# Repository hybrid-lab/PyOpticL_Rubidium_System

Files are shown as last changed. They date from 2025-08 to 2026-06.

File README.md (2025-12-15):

# Rb87 Neutral Atom Optical Platform (PyOpticL + FreeCAD)

This repository contains a PyOpticL-based optical/mechanical layout for building an optical platform targeting Rb-87 neutral atom experiments. It assembles a complete, code-driven CAD model in FreeCAD, organizing the setup into modular boards.

The project originates from (and depends on) PyOpticL, a code-to-CAD tooling framework for modular optics systems engineering, and uses FreeCAD as the CAD backend.

- Project webpage (origin): https://github.com/UMassIonTrappers/PyOpticL
- Affiliation: UC Berkeley, Department of Physics — Prof. Sulyemanzade’s research group
- Lab website: https://suleymanzadelab.com/
- Collaborators:
  - University of Wisconsin-Madison - Prof. Sinclair's research group - https://sinclair.physics.wisc.edu/
  - Dr. Brandon Grinkemeyer, Harvard University (Postdoctoral Researcher) — https://lukin.physics.harvard.edu/people/brandon-grinkemeyer

---
## Overview

- Purpose: Build a modular optical platform for Rb-87 neutral atom quantum computing.
- CAD Backend: FreeCAD
- Optical/CAD Tooling: PyOpticL
- Project Structure: The system is organized into these main boards:
  - Reference_board
  - Laser_board
  - Repumper_board
  - Spectroscopy_board
  - TA_board
  - AOM_board

## Prerequisites

- FreeCAD (latest stable recommended)
- PyOpticL module installed in FreeCAD

---

## Installation

1. Install FreeCAD on your system.
2. Install PyOpticL in FreeCAD, following the official instructions at https://github.com/UMassIonTrappers/PyOpticL.
3. Update the PyOpticL module directory with this project’s assets:
   - Copy the `stl` folder from this repository into the PyOpticL module’s directory.
   - Copy `optomech.py` from this repository into the PyOpticL module’s directory, replacing the existing file if present.

Note: The exact PyOpticL module path depends on your OS and FreeCAD configuration (e.g., on macOS it may be under `~/Library/Application Support/FreeCAD/Mod/PyOpticL/PyOpticL`).

## Project Files

- `stl/` — Mechanical part models used by the layout (mounts, adapters, etc.) in stl format.
- `optomech.py` — Project-specific mechanical and optical component definitions/overrides for PyOpticL.
- `Adapters/` - 3D\-printable files(most of them are in step format) for the adapters on the boards, along with the Rb cell holders.
- Main script: See the provided Python script (e.g., “PyOpticL_Rubidium_System”) that constructs all boards in FreeCAD using PyOpticL.

---

## Boards

- Reference_board:
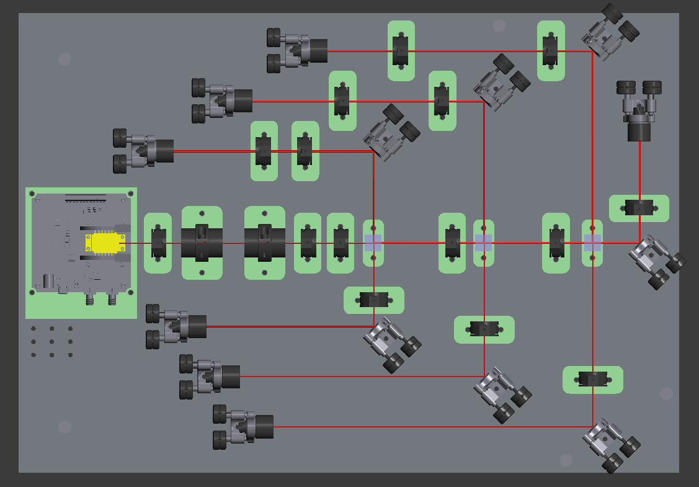
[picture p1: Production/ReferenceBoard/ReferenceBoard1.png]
The schematic of reference board in FreeCAD(front view))

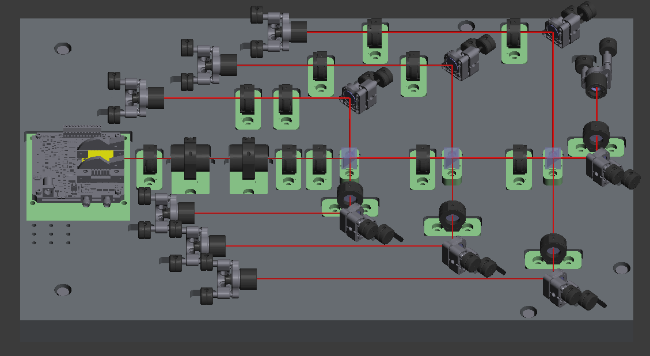
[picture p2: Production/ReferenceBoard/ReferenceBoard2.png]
The schematic of reference board in FreeCAD(top view)

  After exiting the laser, the main beam passes through polarizing elements and isolators, then through several PBSs before entering the fiber, which leads to the Spectroscopy board for frequency locking. Three beams, including the MOT light and Repump light, are each combined with side beams split from the main beam by PBSs, using beatnote technology to achieve frequency locking of these beams.<br><br>

---

- Laser_board:
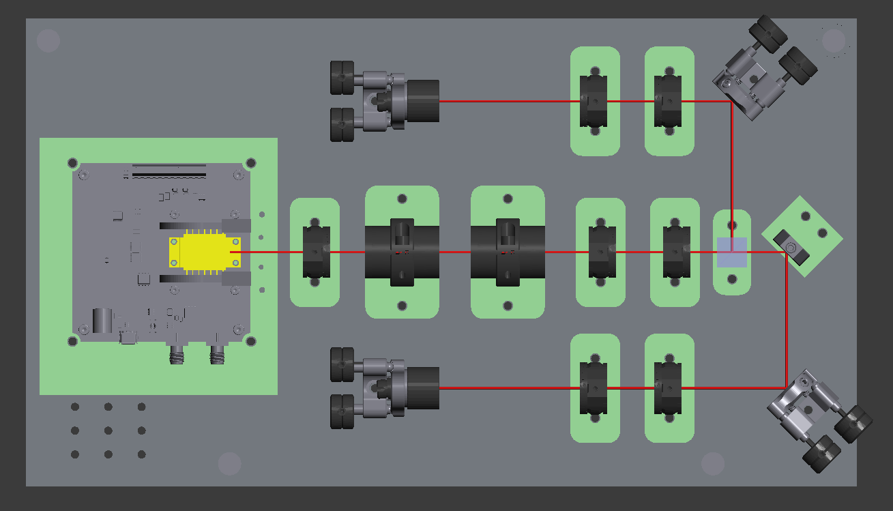
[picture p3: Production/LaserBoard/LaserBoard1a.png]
The schematic of Laser board1 in FreeCAD(front view)
 
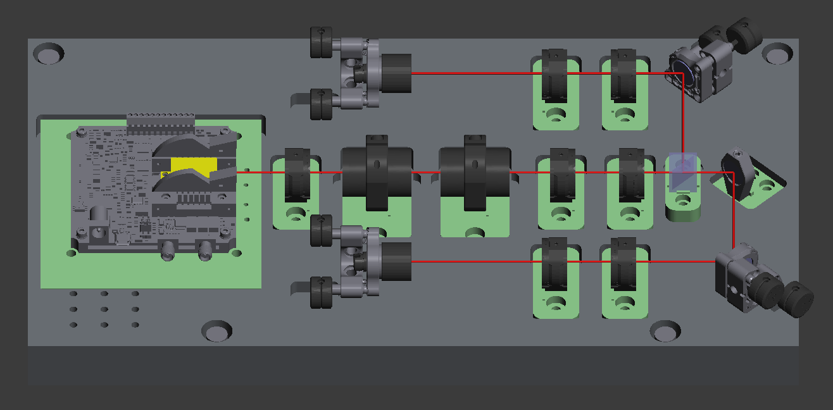
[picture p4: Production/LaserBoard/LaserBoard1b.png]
The schematic of Laser board1 in FreeCAD(top view)
 
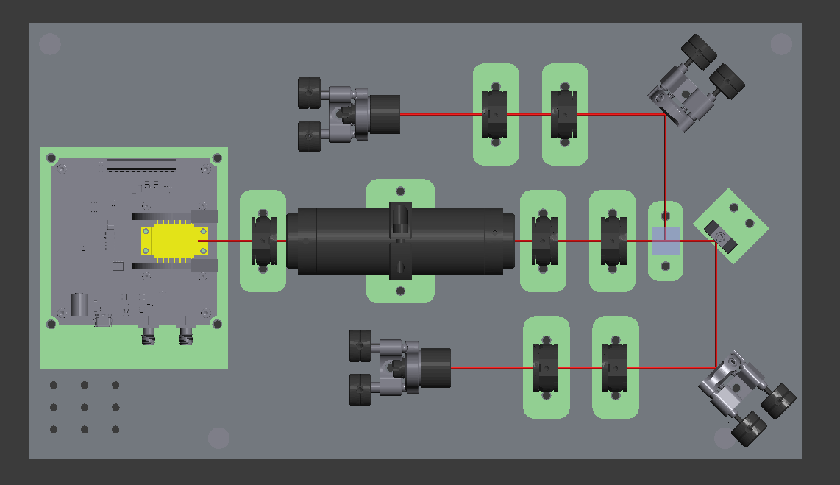
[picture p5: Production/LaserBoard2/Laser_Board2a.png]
The schematic of Laser board2 in FreeCAD(front view)
 
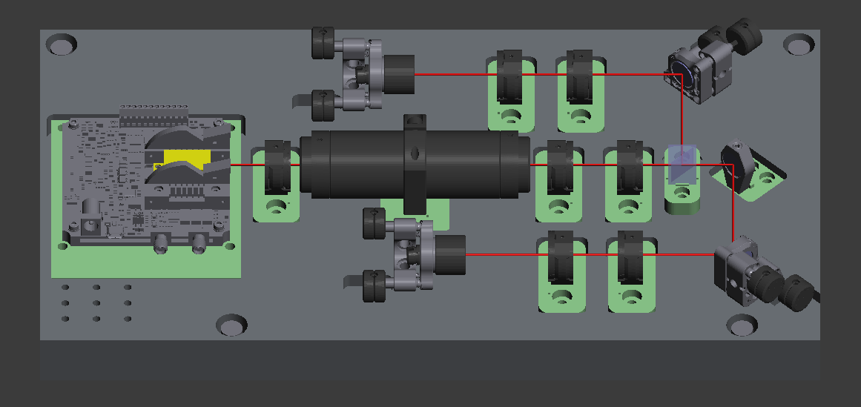
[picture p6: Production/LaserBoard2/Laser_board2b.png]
The schematic of Laser board2 in FreeCAD(top view)
 
The Laser board’s beam splits into two paths: one for various operations (Like MOT and Repumper) and one to the Reference board for frequency locking. 
Because of different types of isolators we may using, there are two versions of the Laser board.<br><br>

---

- Repumper_board:
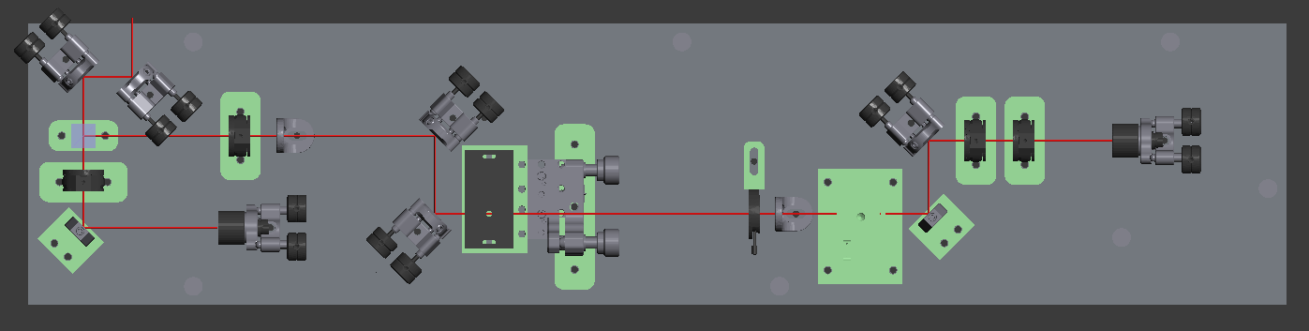
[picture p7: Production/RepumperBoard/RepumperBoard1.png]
The schematic of repumper board in FreeCAD(front view)

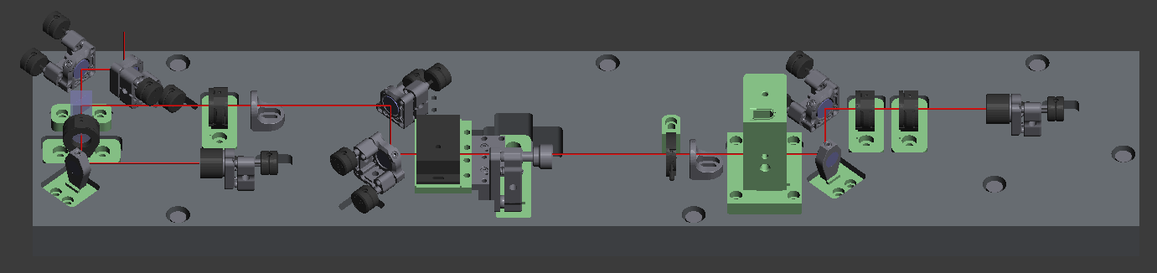
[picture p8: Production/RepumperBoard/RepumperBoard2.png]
The schematic of repumper board in FreeCAD(top view)

The laser board output is sent via fiber to the repumper board (lower left), where a PBS splits it into two beams: one directed to the AOM board (which we likely won’t use for repumping), and the other passing through an AOM and shutter into a fiber.<br><br>

---

- Spectroscopy_board:
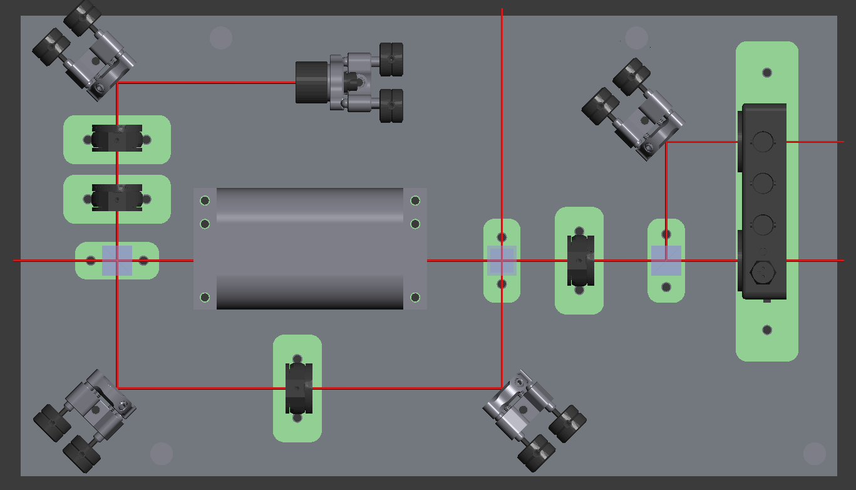
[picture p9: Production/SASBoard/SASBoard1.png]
The schematic of spectroscopy board in FreeCAD(front view)

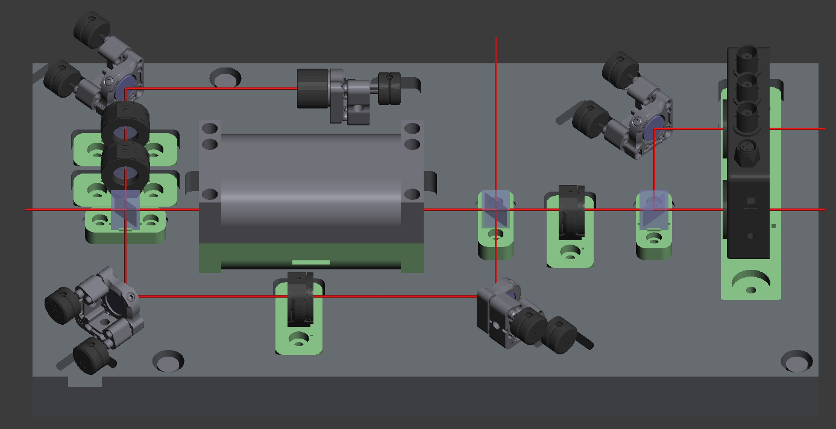
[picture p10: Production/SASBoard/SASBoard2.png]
The schematic of spectroscopy board in FreeCAD(top view)

After going through the reference board, the main beam splits into two beams, one strong(pump) and one weak(probe), which counterpropagate through the Rb atomic vapor at this board. The stronger beam finally goes to the photodetector. Here we use the Saturation absorption spectroscopy method, which will selectively saturate zero-velocity atoms in a vapor, producing a narrow Lamb dip that overcomes Doppler broadening and provides a stable reference for high-precision laser frequency locking.<br><br>

---

- TA_board: 
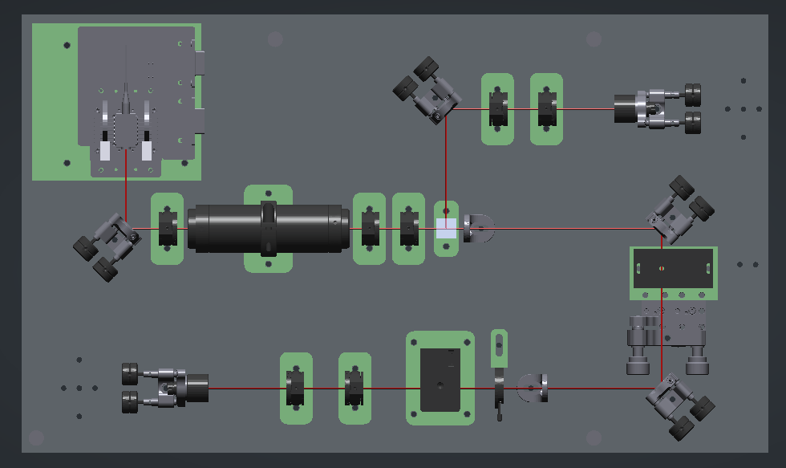
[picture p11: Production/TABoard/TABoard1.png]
The schematic of TA board in FreeCAD(front view)

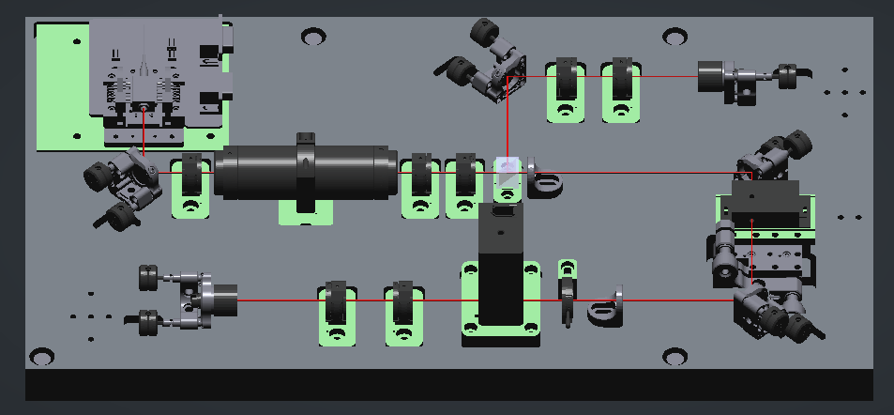
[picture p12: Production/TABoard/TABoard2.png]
The schematic of TA board in FreeCAD(top view)

On this board, a tapered amplifier boosts the laser power before passing it through a -60 dB isolator. The beam is then split into two paths: one leads directly to a fiber for possible coarse locking, while the other passes through an AOM and a shutter before entering a fiber for operations.

---

- AOM_board:
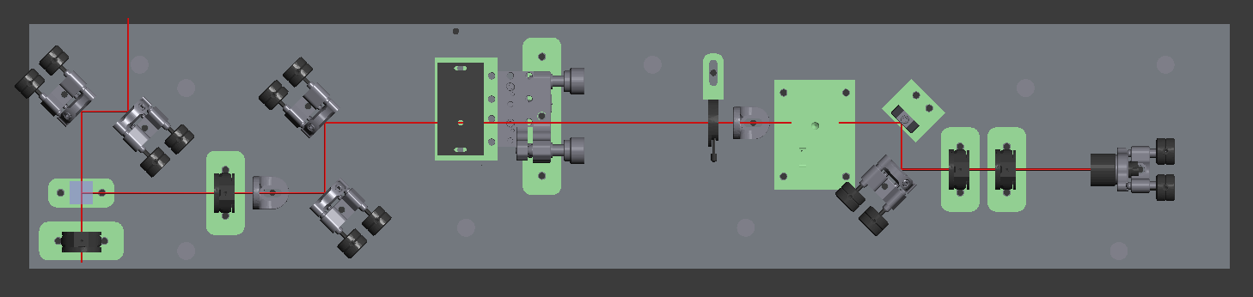
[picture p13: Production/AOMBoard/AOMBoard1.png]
The schematic of AOM board in FreeCAD(front view)

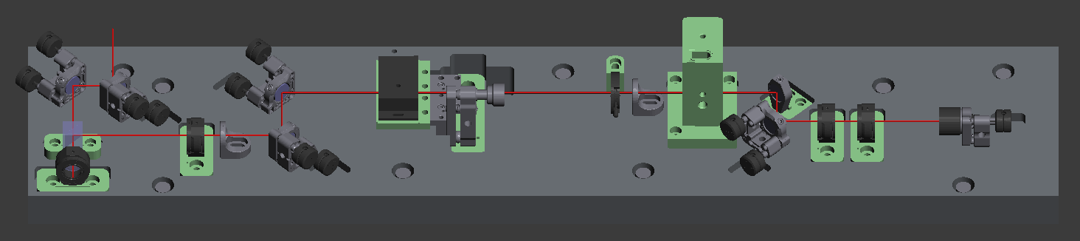
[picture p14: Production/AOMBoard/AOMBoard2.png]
The schematic of AOM board in FreeCAD(top view)

After the TA board, we split the beam into multiple paths, couple each into an optical fiber, and equip each path with an AOM and shutter for switching. This is achieved by combining the Repumper board and AOM board. The TA output is sent via fiber to the repumper board, where a PBS divides it into two beams: one is routed to the appropriately positioned AOM board, and the other passes through an AOM and shutter into a fiber. The beam entering the AOM board is split again: one branch feeds the next AOM board, and the other is coupled into a fiber. This way, we can control the number of beams by adjusting the number of AOM boards.

---
## How to Use

Please see the Quickstart Guide in the PyOpticL wiki:
https://github.com/UMassIonTrappers/PyOpticL/wiki#quickstart-guide

---

## Acknowledgments

**Developed through a collaborative effort between the Department of Physics at the [University of California, Berkeley](https://suleymanzadelab.com/) (Prof. Sulyemanzade’s group) and the [University of Wisconsin–Madison](https://sinclair.physics.wisc.edu/) (Prof. Sinclair’s research group).**  
Additional contributions were provided by [Dr. Brandon Grinkemeyer](https://lukin.physics.harvard.edu/people/brandon-grinkemeyer) (Harvard University, Lukin Group).

The project builds on **PyOpticL**, a code-to-CAD optical layout tool enabling parametric and modular optics design within **FreeCAD**, an open-source parametric 3D CAD modeler used to render and manipulate the generated assemblies.

## Citation

If you use this work in academic settings, please also cite:
- PyOpticL and its associated publications.
- This repository (include commit or release tags).
- UC Berkeley Physics — Sulyemanzade Lab; UW–Madison — Prof. Josiah Sinclair; Harvard University — Dr. Brandon Grinkemeyer.

---

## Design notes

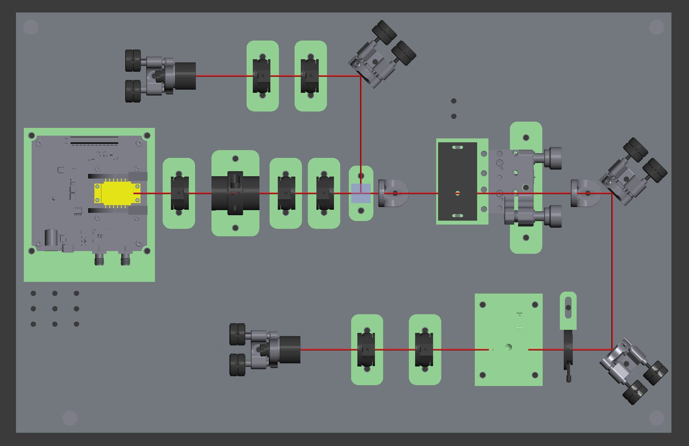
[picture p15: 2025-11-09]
Production/Repumper_consolidated/Repumper_consolidated1.png

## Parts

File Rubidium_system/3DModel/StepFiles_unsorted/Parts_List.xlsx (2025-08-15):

Parts_List
Part Class / Name | Part Number | Qty
lens_tube_sm05l05 | SM05L05 | 2
pinhole_ida12 | IDA12-P5 | 1
fiber_adapter_sm05fca2 | SM05FCA2 | 2
isolator_405 | IO-3D-405-PBS | 1
lens_adapter_s05tm09 | S05TM09 | 2
mirror_mount_km05T_custom | KM05T-8CB-SP | 2
mirror_mount_M05 | Newport-M05 | 3
Koheron_Controller | koheron-CTL200-V5 | 1
lens_holder_l05g | POLARIS-L05G | 2
isomet_1205c_on_km100pm | ISOMET_1205C | 1
circular_lens | LA1213-AB | 2
rotation_stage_rsp05 | RSP05 | 7
prism_mount_km100pm | KM100PM | 1
mounted_lens_c220tmda | C220TMD-A | 2
DFB_butterfly_diode | eyP-BFW01-171218 | 1
Rotation Stage | Unknown | 1
Rotation Stage001 | Unknown | 1
Rotation Stage002 | Unknown | 1
Beam Splitter Cube | Unknown | 1
Mirror | Unknown | 1
Rotation Stage003 | Unknown | 1
Rotation Stage004 | Unknown | 1
Mirror001 | Unknown | 1
Mirror002 | Unknown | 1
Rotation Stage005 | Unknown | 1
Rotation Stage006 | Unknown | 1

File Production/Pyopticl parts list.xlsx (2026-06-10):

3*Laser Board2 |  | 3*TA_Baseplate_V2 |  | 3*Repumper_Baseplate_consolidated |  | 1*SAS Board |  | 1*AOM Board
Adaptors | # | Adapters | # | Adapters | # | Adaptors | # | Adaptors | #
IPS_adapter.step | 1 | TA_adapter.step | 1 | Koheron_adapter.step | 1 | Surface_Adapter_rsp05_lip.step | 4 | FMP05_Adapter.step | 1
FMP05_Adapter.step | 1 | AOM_adapter.step | 1 | AOM_adapter.step | 1 | Rb_Cell_1.stl | 1 | Surface_Adapter_rsp05_lip.step | 4
Surface_Adapter_rsp05_lip.step | 7 | Surface_Adapter_rsp05_lip.step | 7 | Surface_Adapter_rsp05_lip.step | 7 | Rb_Cell_2.stl | 1 | cube_mount_halfinch.step | 1
Surface_Adapter_isolator_lip.step | 1 | Surface_Adapter_isolator_lip.step | 1 | Surface_Adapter_isolator_lip.step | 1 | Surface_Adapter_PD.step | 1 | Surface_Adapter_aom.step | 1
cube_mount_halfinch.step | 1 | cube_mount_halfinch.step | 1 | cube_mount_halfinch.step | 1 | cube_mount_halfinch.step | 3 | AOM_Adapter.step | 1
Laser_Baseplate2.step | 1 | Shutter_adapter.step | 1 | Shutter_adapter.step | 1 | SAS_Baseplate.step | 1 | Iris_Mount.step | 1
 |  | TA_Baseplate2.step |  | Repumper_Baseplate_consolidated.step |  |  |  | Shutter_Adapter.step | 1
 |  |  |  |  |  |  |  | AOM_Baseplate.step | 1
RSP05 (https://www.thorlabs.com/thorproduct.cfm?partnumber=RSP05) | 7 | RSP05 (https://www.thorlabs.com/thorproduct.cfm?partnumber=RSP05) | 7 | RSP05 (https://www.thorlabs.com/thorproduct.cfm?partnumber=RSP05) | 7 | RSP05 (https://www.thorlabs.com/thorproduct.cfm?partnumber=RSP05) | 4 | RSP05 (https://www.thorlabs.com/thorproduct.cfm?partnumber=RSP05) | 4
IOT-5-850-MP (https://www.thorlabs.com/thorproduct.cfm?partnumber=IOT-5-850-MP) | 1
 |  | IO-3D-780-VLP (https://www.thorlabs.com/thorproduct.cfm?partnumber=IO-3D-780-VLP) | 1 | IO-3D-780-VLP (https://www.thorlabs.com/thorproduct.cfm?partnumber=IO-3D-780-VLP) | 1
KA05T (https://www.thorlabs.com/thorproduct.cfm?partnumber=KA05T) | 2 | KA05T (https://www.thorlabs.com/thorproduct.cfm?partnumber=KA05T) | 2 | KA05T (https://www.thorlabs.com/thorproduct.cfm?partnumber=KA05T) | 2 | KA05T (https://www.thorlabs.com/thorproduct.cfm?partnumber=KA05T) | 1 | KM05T (https://www.thorlabs.com/thorproduct.cfm?partnumber=KM05T) | 1
SM05L05 (https://www.thorlabs.com/thorproduct.cfm?partnumber=SM05L05) | 2 | SM05L05 (https://www.thorlabs.com/thorproduct.cfm?partnumber=SM05L05) | 2 | SM05L05 (https://www.thorlabs.com/thorproduct.cfm?partnumber=SM05L05) | 2 | SM05L05 (https://www.thorlabs.com/thorproduct.cfm?partnumber=SM05L05) | 1 | SM05L05 (https://www.thorlabs.com/thorproduct.cfm?partnumber=SM05L05) | 1
SM05FCA2 (https://www.thorlabs.com/thorproduct.cfm?partnumber=SM05FCA2) | 2 | SM05FCA2 (https://www.thorlabs.com/thorproduct.cfm?partnumber=SM05FCA2) | 2 | SM05FCA2 (https://www.thorlabs.com/thorproduct.cfm?partnumber=SM05FCA2) | 2 | SM05FCA2 (https://www.thorlabs.com/thorproduct.cfm?partnumber=SM05FCA2) | 1 | SM05FCA2 (https://www.thorlabs.com/thorproduct.cfm?partnumber=SM05FCA2) | 1
S05TM09 (https://www.thorlabs.com/thorproduct.cfm?partnumber=S05TM09) | 2 | S05TM09 (https://www.thorlabs.com/thorproduct.cfm?partnumber=S05TM09) | 2 | S05TM09 (https://www.thorlabs.com/thorproduct.cfm?partnumber=S05TM09) | 2 | S05TM09 (https://www.thorlabs.com/thorproduct.cfm?partnumber=S05TM09) | 1 | S05TM09 (https://www.thorlabs.com/thorproduct.cfm?partnumber=S05TM09) | 1
M05 (https://www.newport.com/p/M05) | 2 | M05 (https://www.newport.com/p/M05) | 3 | M05 (https://www.newport.com/p/M05) | 3 | M05 (https://www.newport.com/p/M05) | 4 | M05 (https://www.newport.com/p/M05) | 5
FMP05 (http://thorlabs.com/thorproduct.cfm?partnumber=FMP05) | 1 |  |  |  |  |  |  | FMP05 (http://thorlabs.com/thorproduct.cfm?partnumber=FMP05) | 1
BB05-E03 (https://www.thorlabs.com/thorproduct.cfm?partnumber=BB05-E03) | 2 | BB05-E03 (https://www.thorlabs.com/thorproduct.cfm?partnumber=BB05-E03) | 3 | BB05-E03 (https://www.thorlabs.com/thorproduct.cfm?partnumber=BB05-E03) | 3 | BB05-E03 (https://www.thorlabs.com/thorproduct.cfm?partnumber=BB05-E03) | 4 | BB05-E03 (https://www.thorlabs.com/thorproduct.cfm?partnumber=BB05-E03) | 5
 |  | LA1614-B (https://www.thorlabs.com/thorproduct.cfm?partnumber=LA1614-B) | 2 | LA1614-B (https://www.thorlabs.com/thorproduct.cfm?partnumber=LA1614-B) | 2
 |  |  |  |  |  |  |  | LA4004-AB (https://www.thorlabs.de/thorproduct.cfm?partnumber=LA4004-AB) | 2
 |  | AOMO_3100_125 (https://gandh.com/products/acousto-optics/modulators/aomo-3100-125) | 1 | AOMO_3100_125 (https://gandh.com/products/acousto-optics/modulators/aomo-3100-125) | 1 |  |  | AOMO_3100_125 (https://gandh.com/products/acousto-optics/modulators/aomo-3100-125) | 1
 |  | Iris (https://www.thorlabs.us/thorproduct.cfm?partnumber=IDA12-P5) | 1 | Iris (https://www.thorlabs.us/thorproduct.cfm?partnumber=IDA12-P5) | 1 |  |  | iris (https://www.thorlabs.us/thorproduct.cfm?partnumber=IDA12-P5) | 1
 |  | SRS SR475 Shutter (https://www.thinksrs.com/products/sr470474.html) | 1 | SRS SR475 Shutter (https://www.thinksrs.com/products/sr470474.html) | 1 |  |  | SRS SR475 Shutter (https://www.thinksrs.com/products/sr470474.html) | 1
 |  |  |  |  |  | Rb Vapor Cell (https://www.thorlabs.com/thorproduct.cfm?partnumber=GC25075-RB) | 1
 |  |  |  |  |  | PD (https://www.thorlabs.com/thorproduct.cfm?partnumber=PDB250A) | 1
cube | 1 | cube | 1 | cube | 1 | cube | 3 | cube | 2
 | 3*Laser Board2 | 6*TA_Baseplate_V2 | 0*Repumper_Baseplate_consolidated | 2*SAS Board | 0*AOM Board | Total
RSP05 (https://www.thorlabs.com/thorproduct.cfm?partnumber=RSP05) | 7 | 7 | 7 | 4 | 4 | 71
IOT-5-850-MP (https://www.thorlabs.com/thorproduct.cfm?partnumber=IOT-5-850-MP) | 1 | 0 | 0 | 0 | 0 | 3
IO-3D-780-VLP (https://www.thorlabs.com/thorproduct.cfm?partnumber=IO-3D-780-VLP) | 0 | 1 | 1 | 0 | 0 | 6
KA05T (https://www.thorlabs.com/thorproduct.cfm?partnumber=KA05T) | 2 | 2 | 2 | 1 | 1 | 20
SM05L05 (https://www.thorlabs.com/thorproduct.cfm?partnumber=SM05L05) | 2 | 2 | 2 | 1 | 1 | 20
SM05FCA2 (https://www.thorlabs.com/thorproduct.cfm?partnumber=SM05FCA2) | 2 | 2 | 2 | 1 | 1 | 20
S05TM09 (https://www.thorlabs.com/thorproduct.cfm?partnumber=S05TM09) | 2 | 2 | 2 | 1 | 1 | 20
M05 (https://www.newport.com/p/M05) | 2 | 3 | 3 | 4 | 5 | 32
FMP05 (http://thorlabs.com/thorproduct.cfm?partnumber=FMP05) | 1 | 0 | 0 | 0 | 1 | 3
BB05-E03 (https://www.thorlabs.com/thorproduct.cfm?partnumber=BB05-E03) | 2 | 3 | 3 | 4 | 5 | 32
LA1614-B (https://www.thorlabs.com/thorproduct.cfm?partnumber=LA1614-B) | 0 | 2 | 2 | 0 | 0 | 12
LA4004-AB (https://www.thorlabs.de/thorproduct.cfm?partnumber=LA4004-AB) | 0 | 0 | 0 | 0 | 2 | 0
AOMO_3100_125 (https://gandh.com/products/acousto-optics/modulators/aomo-3100-125) | 0 | 1 | 1 | 0 | 1 | 6
Iris (https://www.thorlabs.us/thorproduct.cfm?partnumber=IDA12-P5) | 0 | 1 | 1 | 0 | 1 | 6
SRS SR475 Shutter (https://www.thinksrs.com/products/sr470474.html) | 0 | 1 | 1 | 0 | 1 | 6
Rb Vapor Cell (https://www.thorlabs.com/thorproduct.cfm?partnumber=GC25075-RB) | 0 | 0 | 0 | 1 | 0 | 2
PD (https://www.thorlabs.com/thorproduct.cfm?partnumber=PDB250A) | 0 | 0 | 0 | 1 | 0 | 2
cube | 1 | 1 | 1 | 3 | 1 | 15

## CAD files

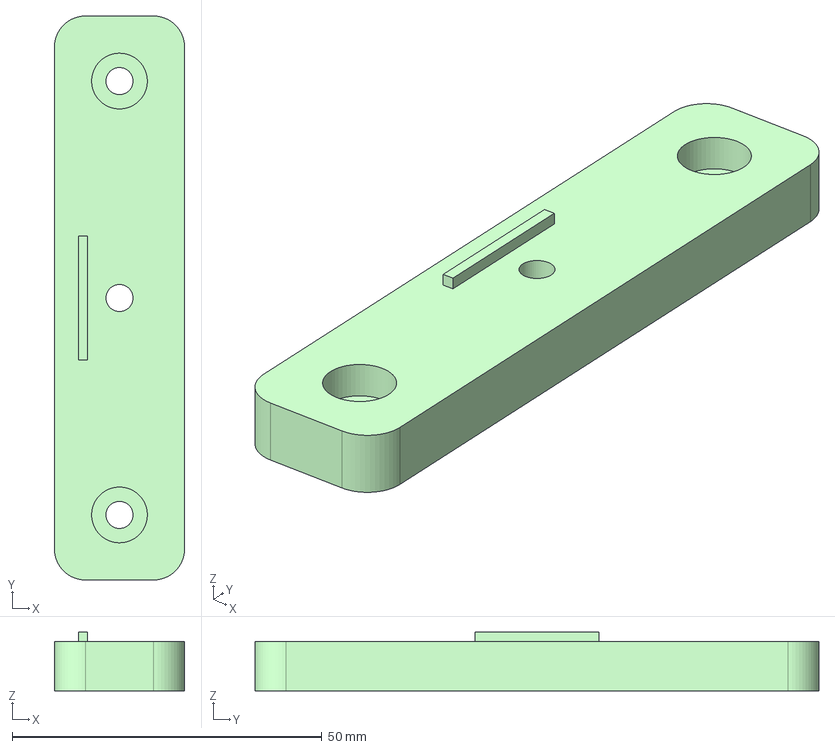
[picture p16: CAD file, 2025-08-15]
Adapters/Surface_Adapter_wide_lip.step
21.0 x 91.0 x 9.50 mm

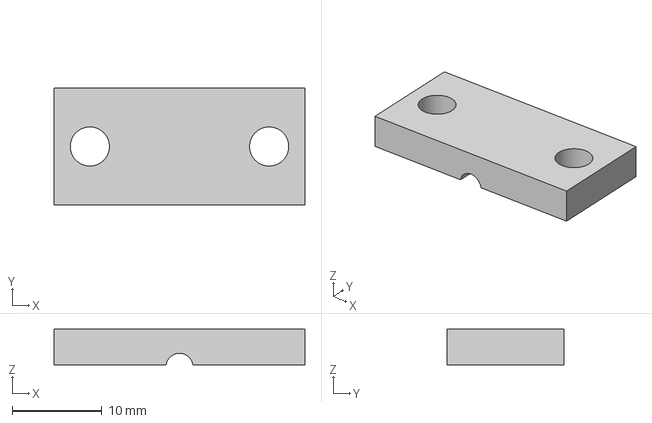
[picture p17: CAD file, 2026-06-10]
Production/Adapters/Fiber_Clamp_3_top.step
28.0 x 13.0 x 4.00 mm

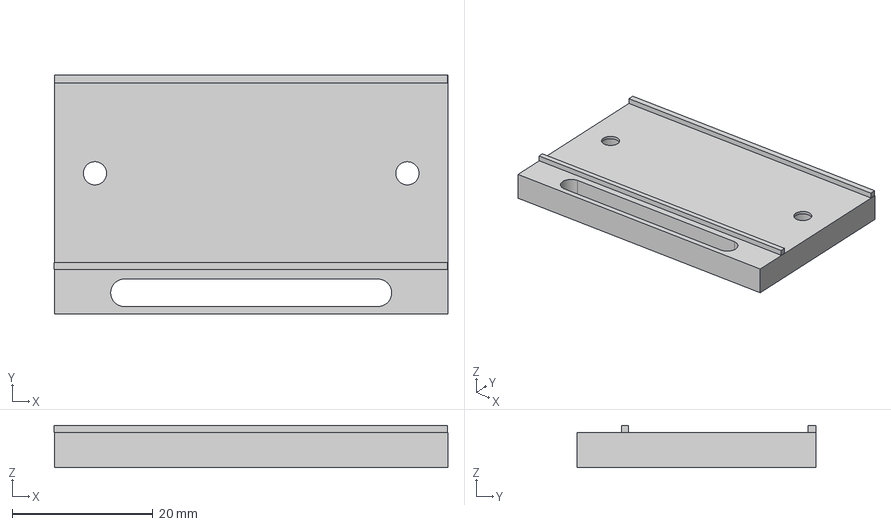
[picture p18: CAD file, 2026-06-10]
Production/Adapters/Stepfile/AOM_Adapter.step
56.1 x 34.0 x 6.00 mm

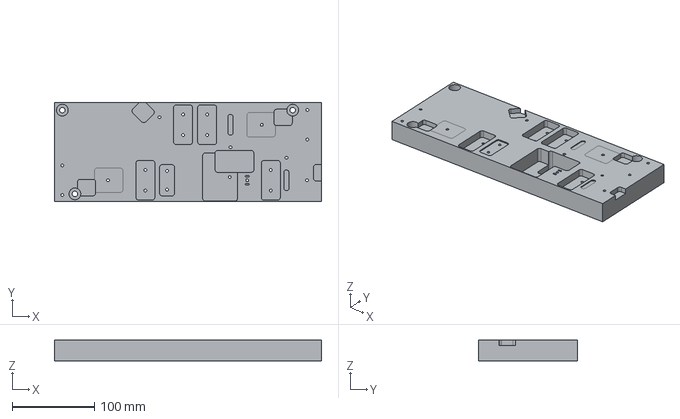
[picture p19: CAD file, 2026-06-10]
Production/AOM_Doublepass/AOM_doublepass_revised.step
323.8 x 120.7 x 25.4 mm

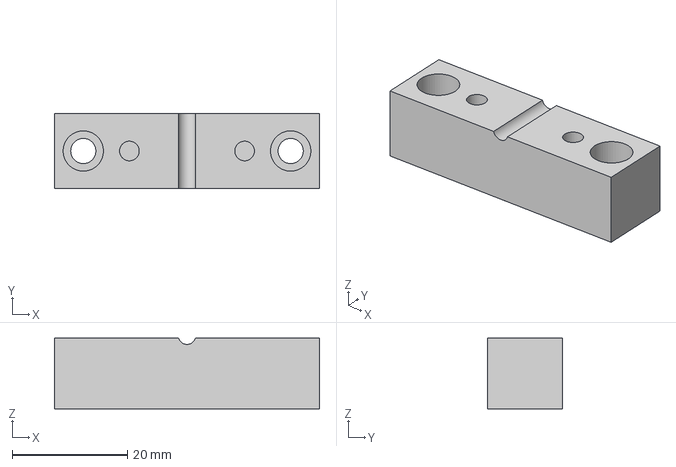
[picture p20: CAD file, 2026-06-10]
Production/AOM_Doublepass/StepFile/Fiber_Clamp_3_bottom.step
46.0 x 13.0 x 12.3 mm

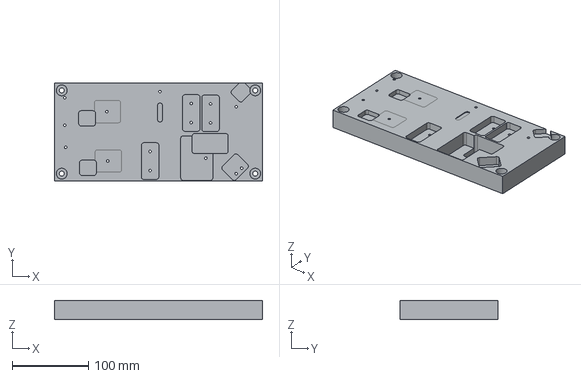
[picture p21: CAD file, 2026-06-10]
Production/AOM_Singlepass/AOM_Singlepass.step
273.1 x 128.3 x 25.4 mm

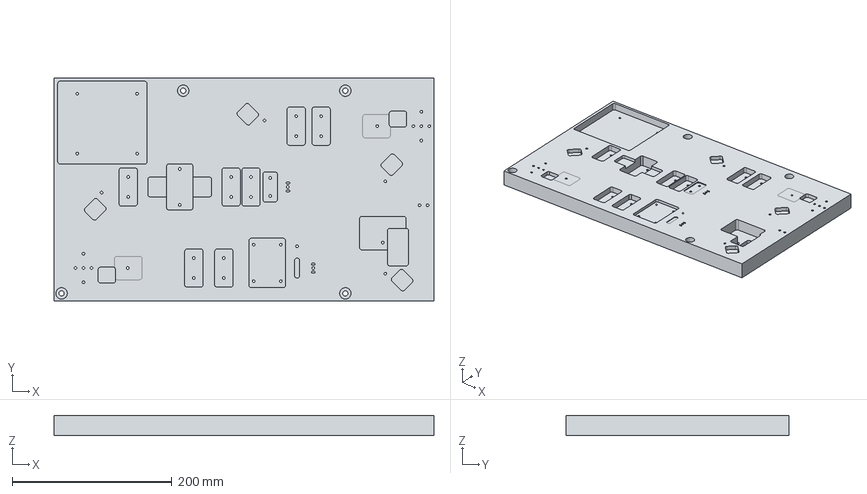
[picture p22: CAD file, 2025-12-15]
Production/Baseplate/TA_Laser-Baseplate.step
476.2 x 279.4 x 25.4 mm

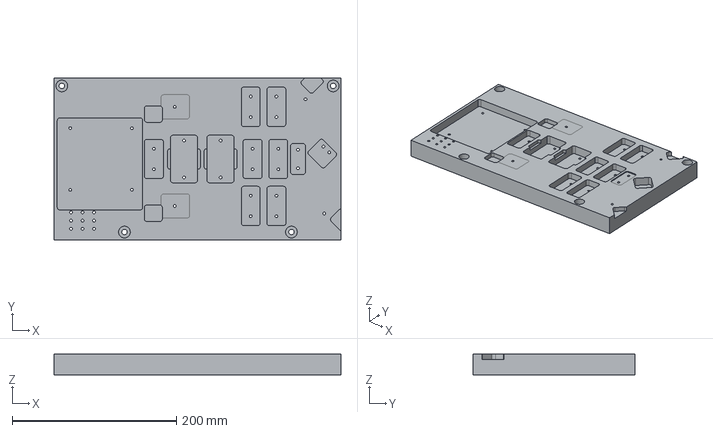
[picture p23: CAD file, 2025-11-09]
Production/LaserBoard/StepFile/Laser_Baseplate1.step
349.2 x 196.8 x 25.4 mm

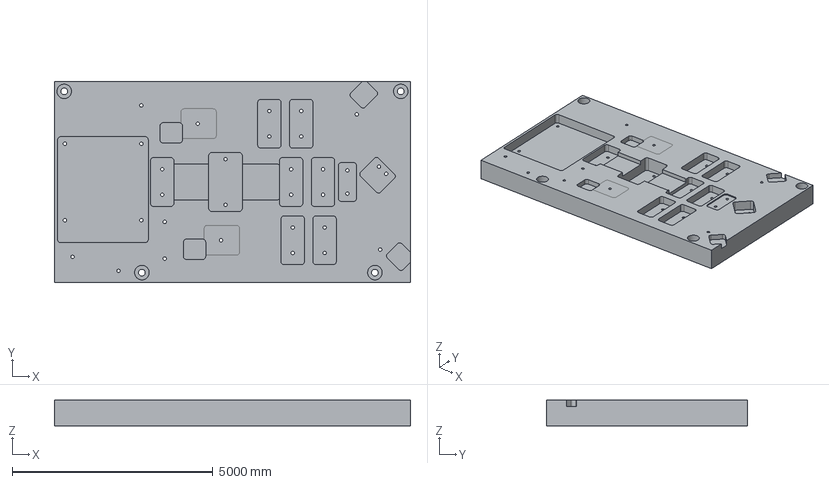
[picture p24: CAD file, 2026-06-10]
Production/LaserBoard2/StepFile/Laser_Baseplate2.step
8870.9 x 5000.0 x 645.2 mm

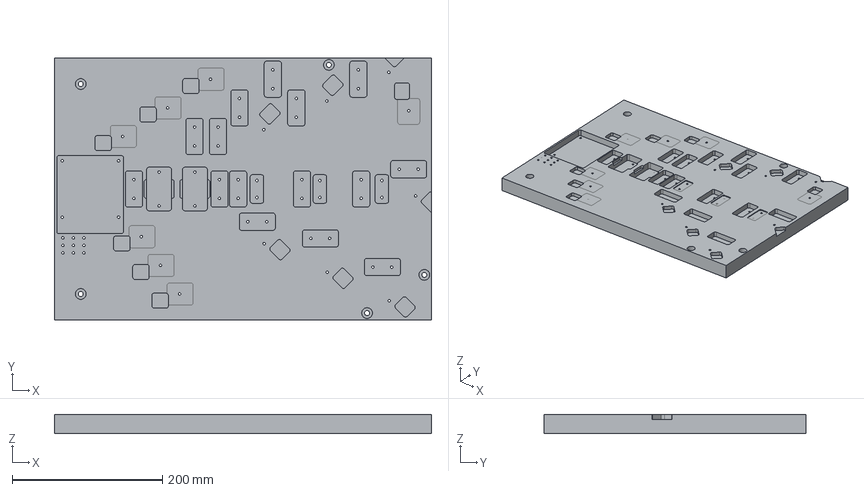
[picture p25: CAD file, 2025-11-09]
Production/ReferenceBoard/StepFile/Reference_Baseplate.step
501.6 x 349.2 x 25.4 mm

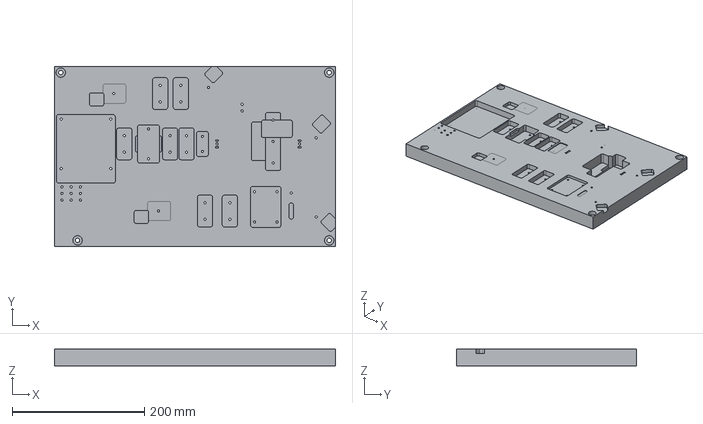
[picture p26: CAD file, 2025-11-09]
Production/Repumper_consolidated/StepFile/Repumper_Baseplate_consolidated.step
425.4 x 273.1 x 25.4 mm

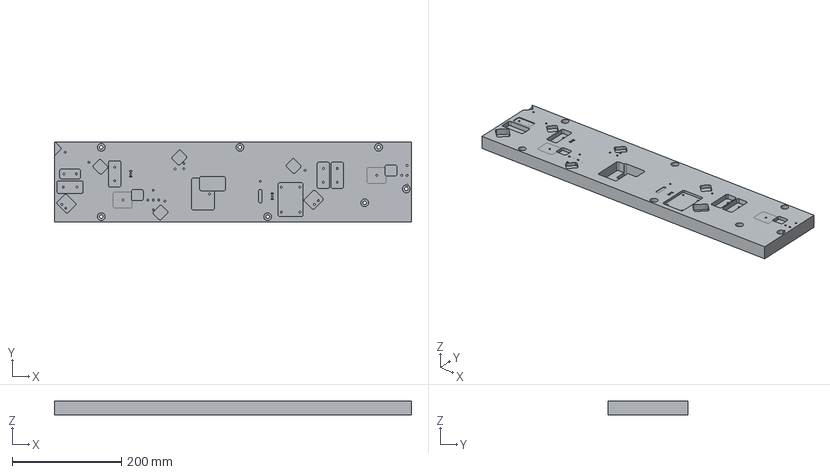
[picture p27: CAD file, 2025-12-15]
Production/RepumperBoard/StepFile/Repumper_Baseplate.step
654.1 x 146.0 x 25.4 mm

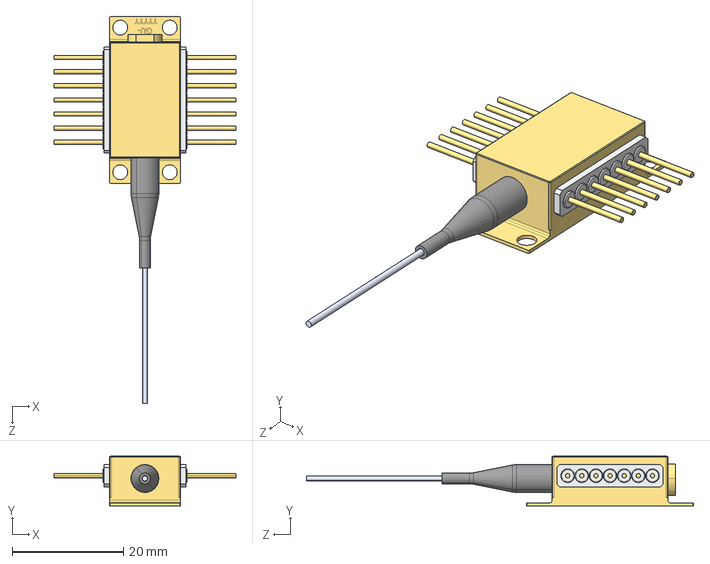
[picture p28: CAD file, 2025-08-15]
Rubidium_system/3DModel/Eagleyard/eyP-BTUx9-SWB-22-0823-1000.STEP
32.7 x 8.90 x 69.6 mm

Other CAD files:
Oriented Step Files/M05-X.step
Production/AOMBoard/StepFile/AOM_Adapter.step
Production/SASBoard/StepFile/SAS_Baseplate.step
Adapters/AOM_Adapter.step
Adapters/Cube_Mount.step
Adapters/PD_Mount.step
Adapters/Rb_Cell_1.stl
Adapters/Rb_Cell_2.stl
Adapters/Surface_Adapter_FIberport_rotate_lip.step
Adapters/Surface_Adapter_PD.step
Adapters/shutter_adapter.step
Oriented Step Files/IPS_laser.step
Oriented Step Files/KA05A.step
Oriented Step Files/KA05D.step
Oriented Step Files/KA05T.step
Oriented Step Files/MRA12-E03.step
Oriented Step Files/eyP-BFW01-171218.step
Production/AOMBoard/StepFile/AOM_Baseplate.step
Production/AOM_Doublepass/AOM_doublepass.step
Production/AOM_Doublepass/StepFile/AOM_Adapter.step
Production/AOM_Doublepass/StepFile/Cube_Mount_Halfinch.step
Production/AOM_Doublepass/StepFile/Cube_Mount_Halfinch_2taps.step
Production/AOM_Doublepass/StepFile/Iris_Adapter.step
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

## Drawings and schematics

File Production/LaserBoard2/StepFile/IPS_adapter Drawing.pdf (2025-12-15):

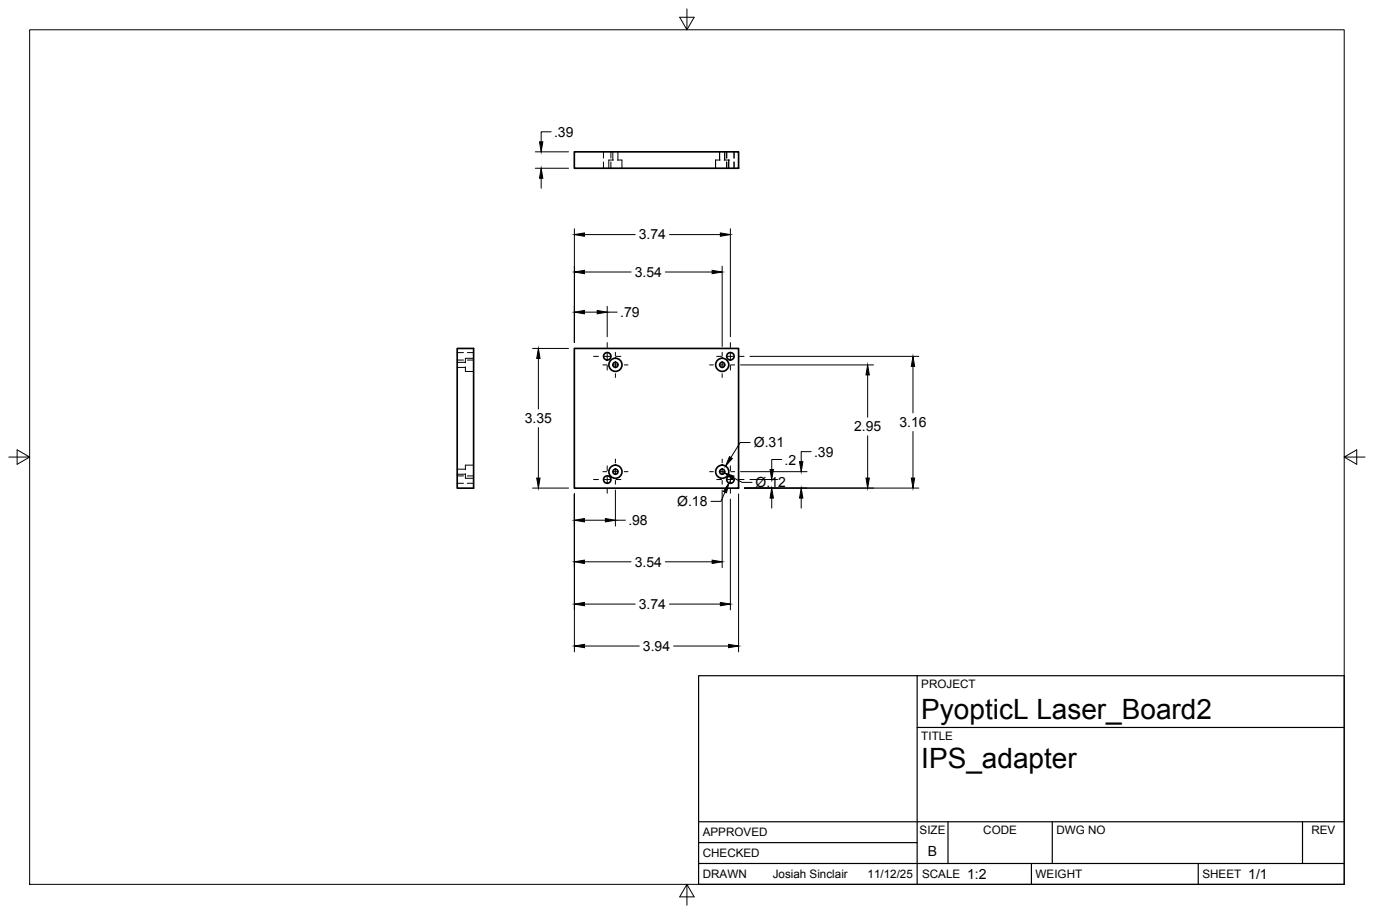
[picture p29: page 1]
SIZE; CODE; DWG NO; REV; Josiah Sinclair; PyopticL Laser_Board2

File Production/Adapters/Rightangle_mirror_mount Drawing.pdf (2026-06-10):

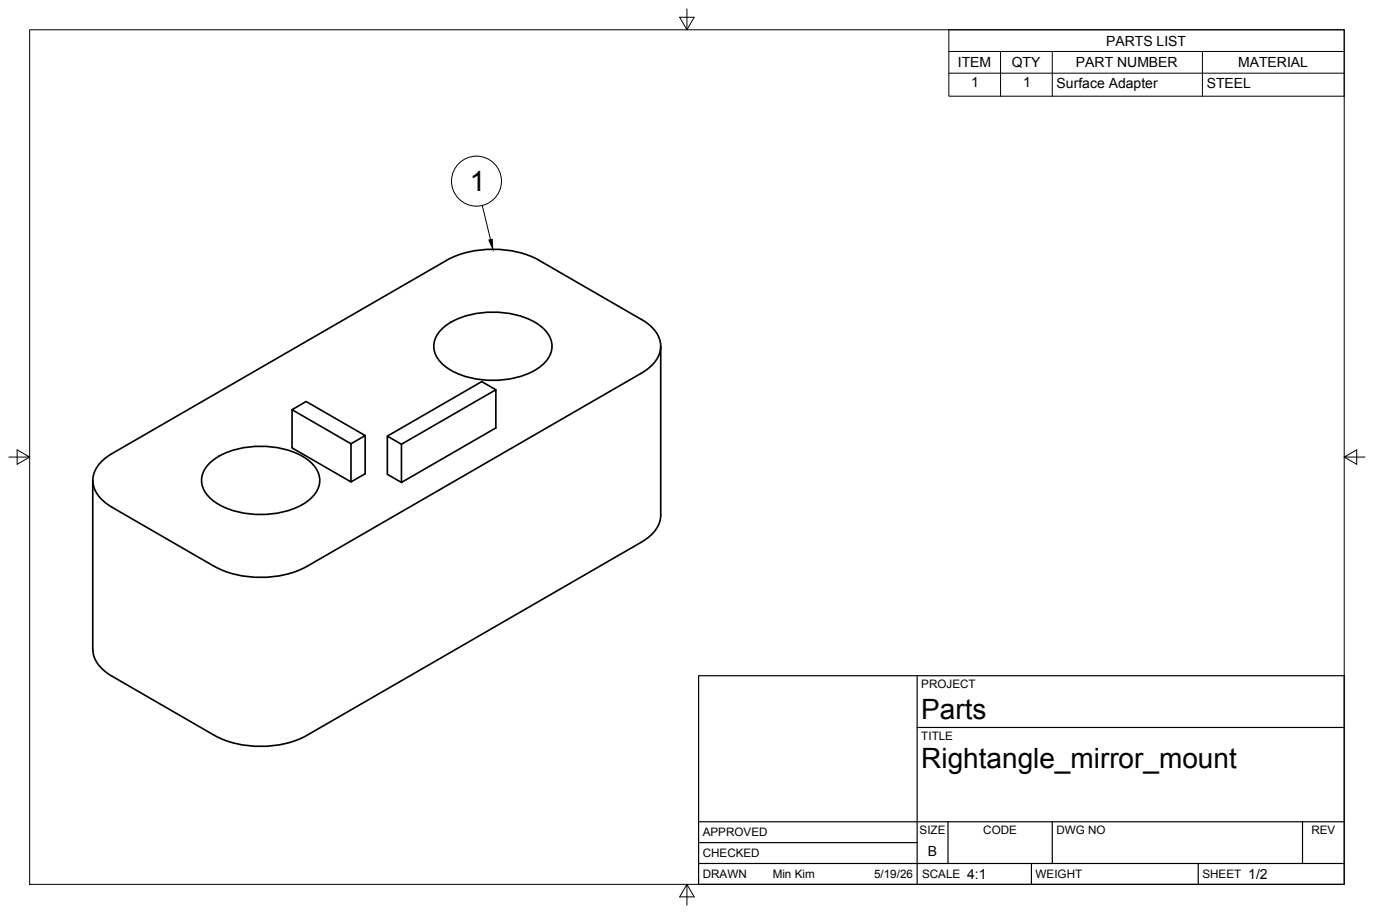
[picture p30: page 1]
SIZE; CODE; DWG NO; REV; Min Kim; PARTS LIST

ITEM | QTY | PART NUMBER | MATERIAL
1 | 1 | Surface Adapter | STEEL

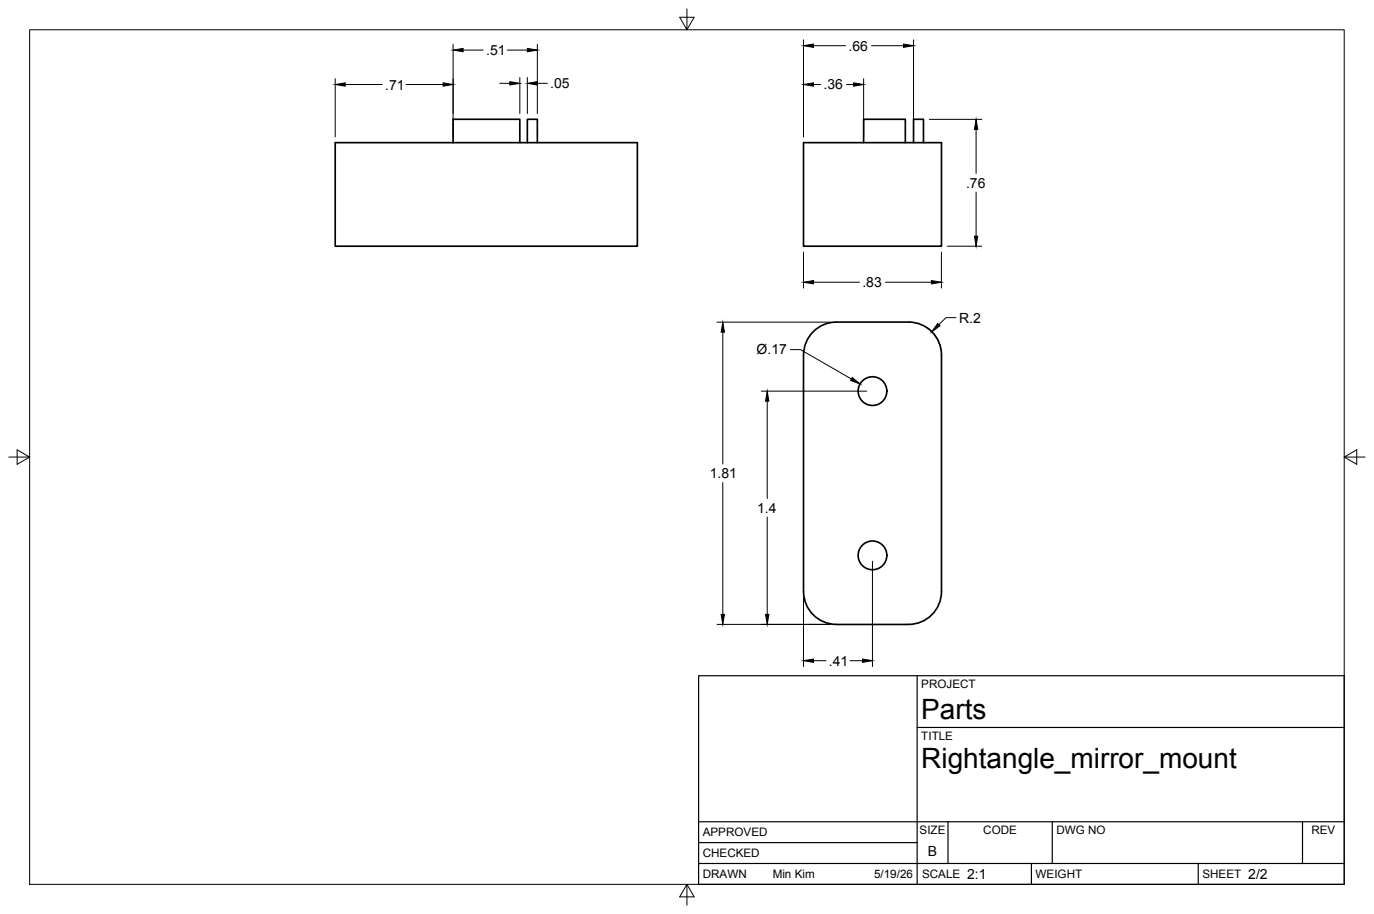
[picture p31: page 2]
SIZE; CODE; DWG NO; REV; Min Kim

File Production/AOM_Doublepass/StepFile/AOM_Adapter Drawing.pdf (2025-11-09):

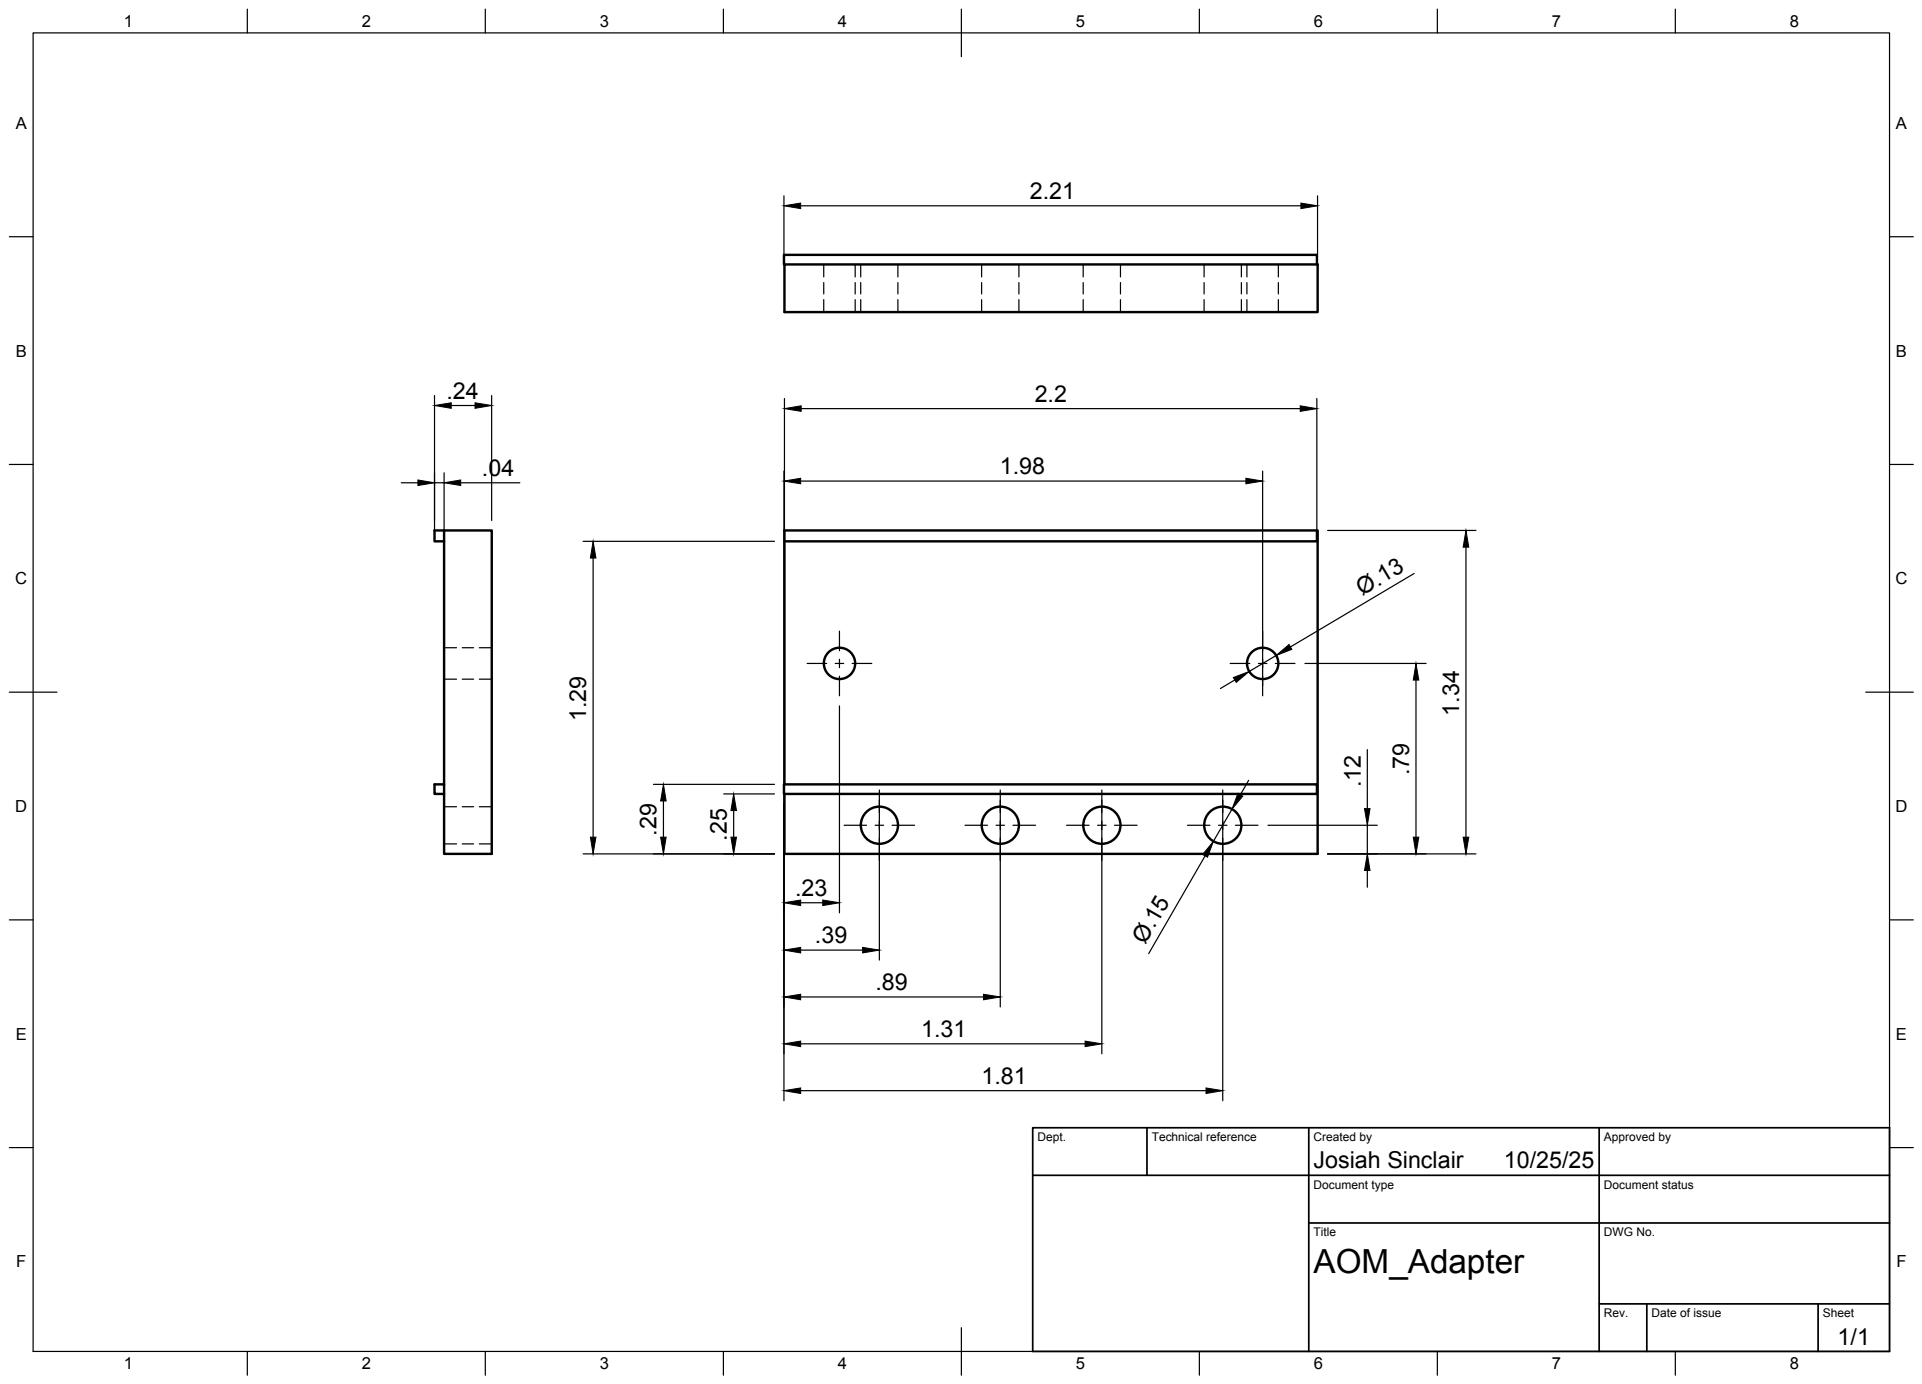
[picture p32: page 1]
Title; DWG No.; Rev.; Date of issue; Sheet; Josiah Sinclair1.34

Dept. | Technical reference | Created by 10/25/25 | Approved by

Document type | Document status

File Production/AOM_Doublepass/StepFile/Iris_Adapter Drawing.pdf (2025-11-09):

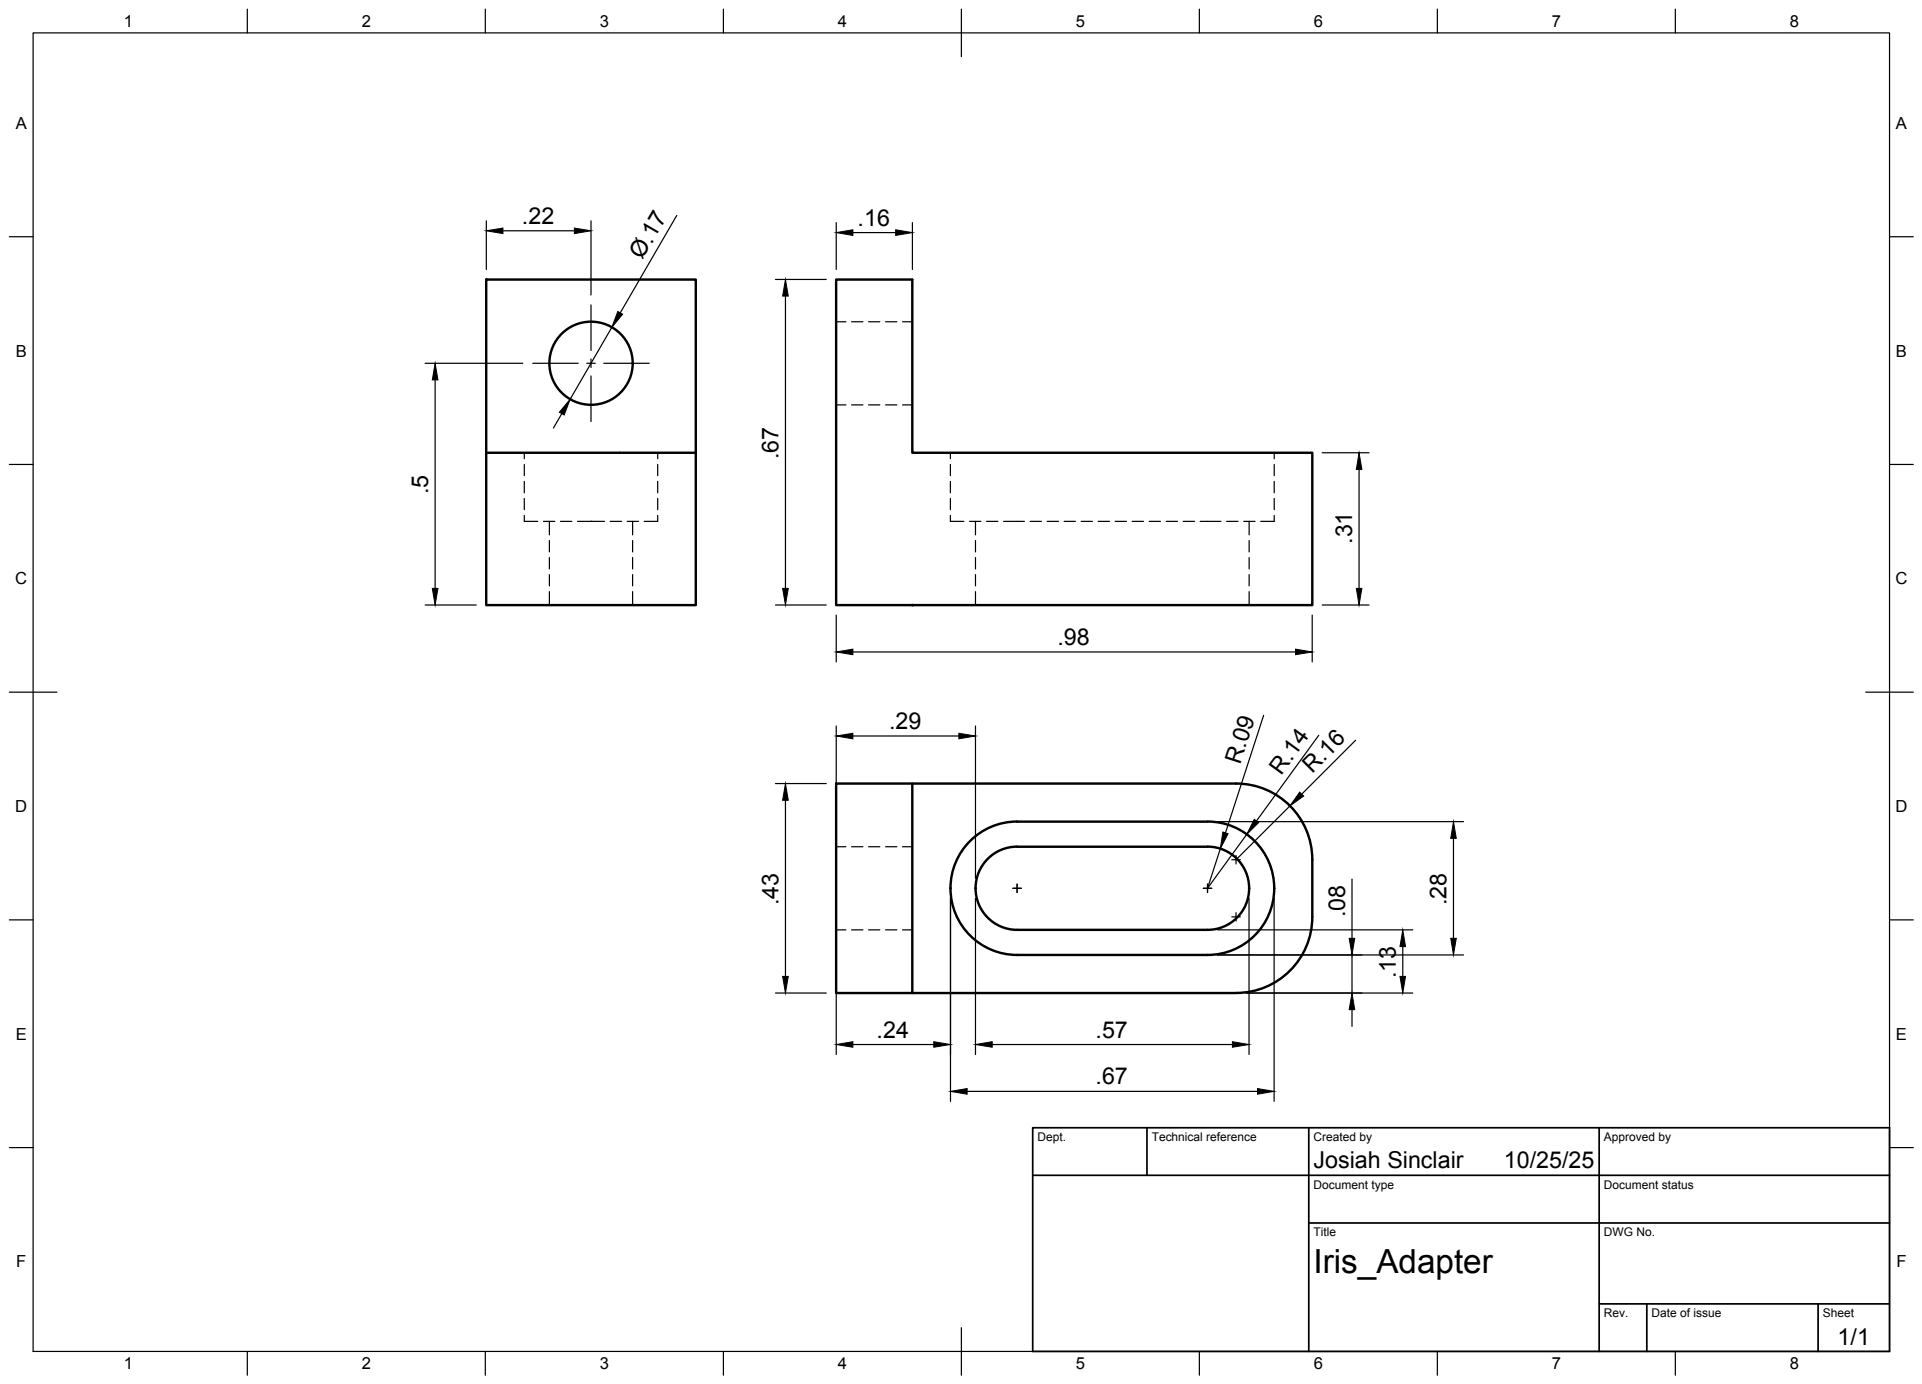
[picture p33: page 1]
Title; DWG No.; Rev.; Date of issue; Sheet

Dept. | Technical reference | Created by Josiah Sinclair 10/25/25 | Approved by

Document type | Document status

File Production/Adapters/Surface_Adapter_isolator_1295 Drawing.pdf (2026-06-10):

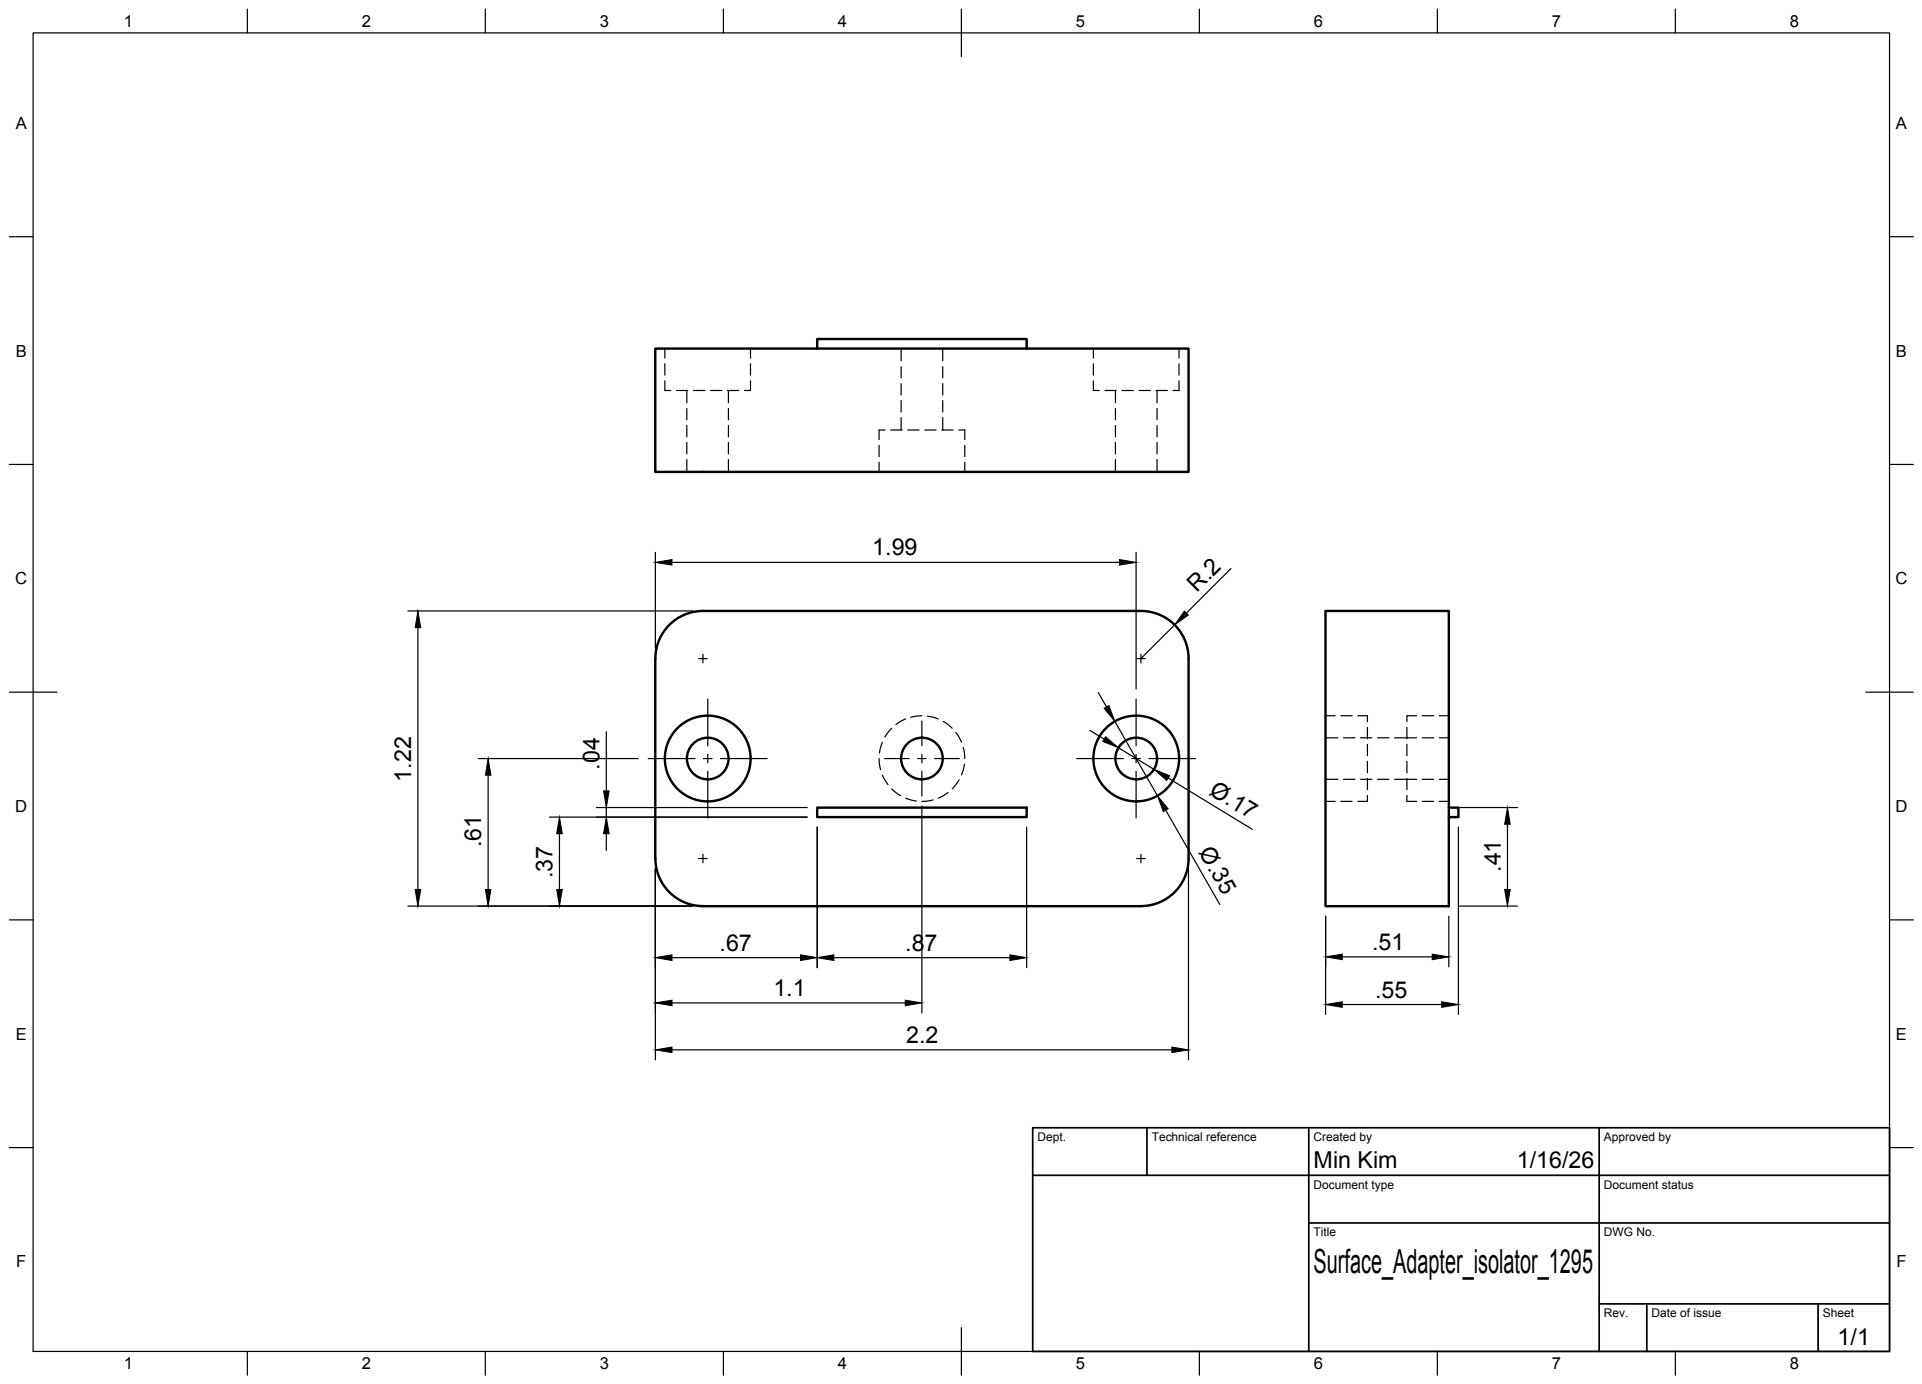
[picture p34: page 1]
Title; DWG No.; Rev.; Date of issue; Sheet

Dept. | Technical reference | Created by Min Kim 1/16/26 | Approved by

Document type | Document status

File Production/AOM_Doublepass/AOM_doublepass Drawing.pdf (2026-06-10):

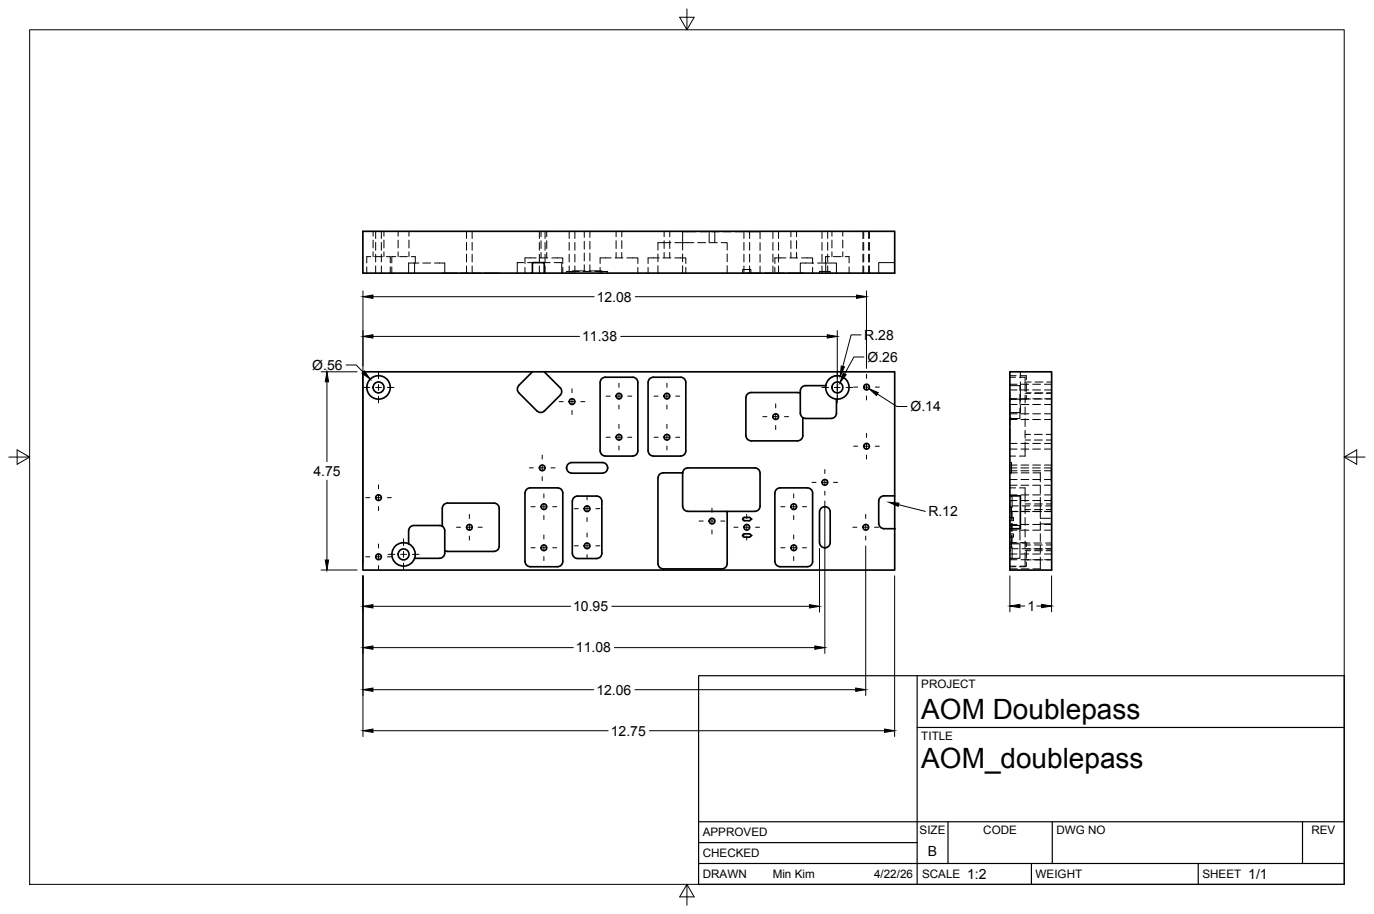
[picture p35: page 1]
SIZE; CODE; DWG NO; REV; Min Kim; AOM Doublepass

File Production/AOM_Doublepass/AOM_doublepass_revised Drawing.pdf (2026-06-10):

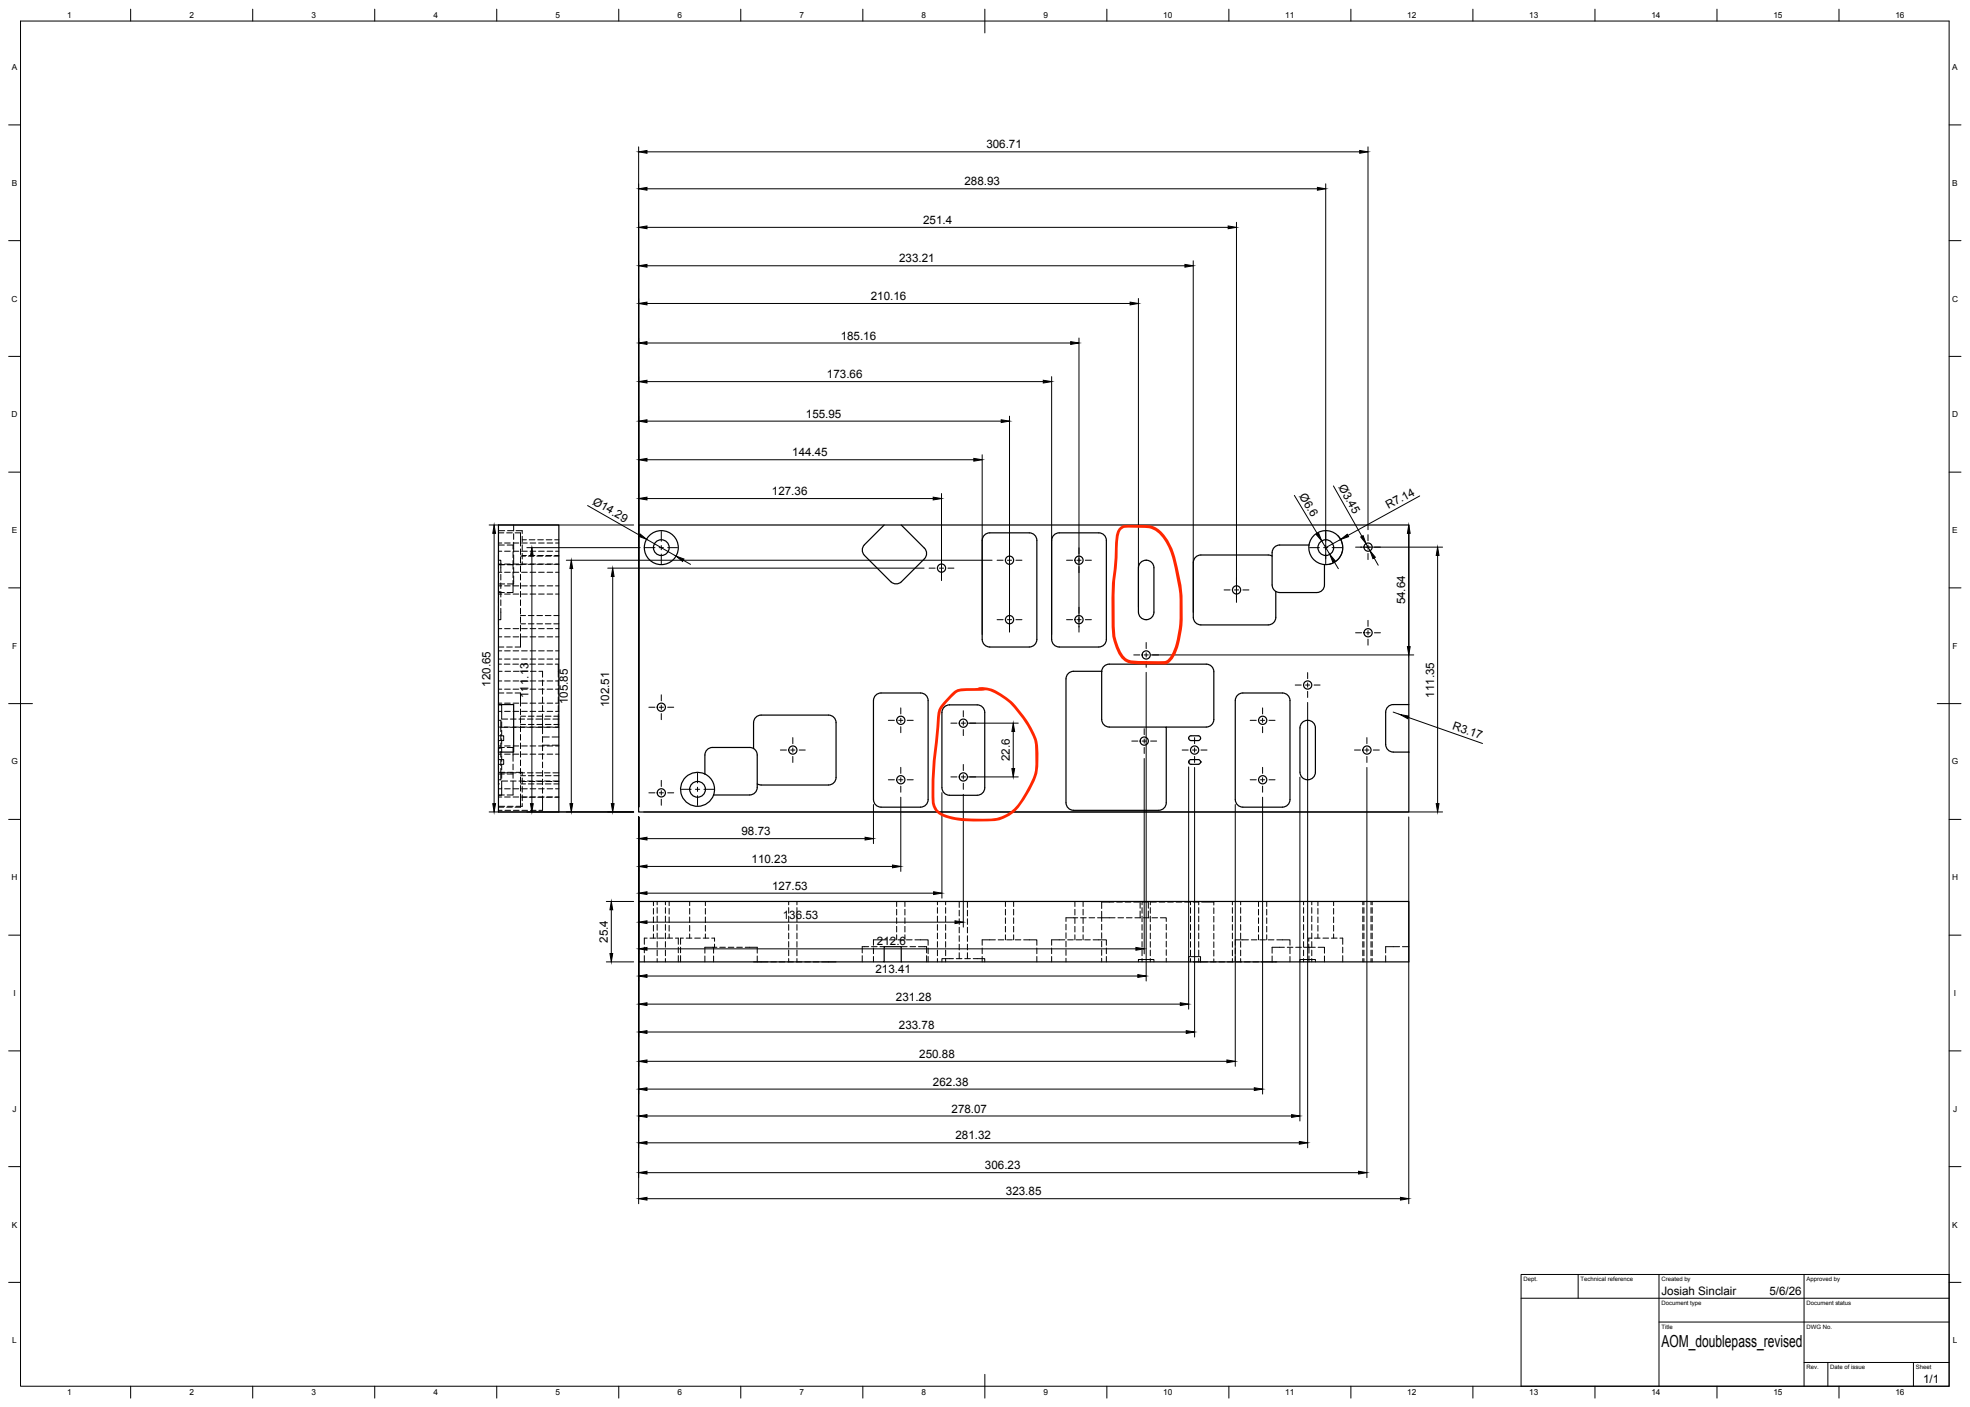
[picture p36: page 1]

Dept. | Technical reference | Created by Josiah Sinclair 5/6/26 | Approved by

Document type | Document status

Title AOM_doublepass_revised | DWG No.

Rev. | Date of issue | Sheet 1/1

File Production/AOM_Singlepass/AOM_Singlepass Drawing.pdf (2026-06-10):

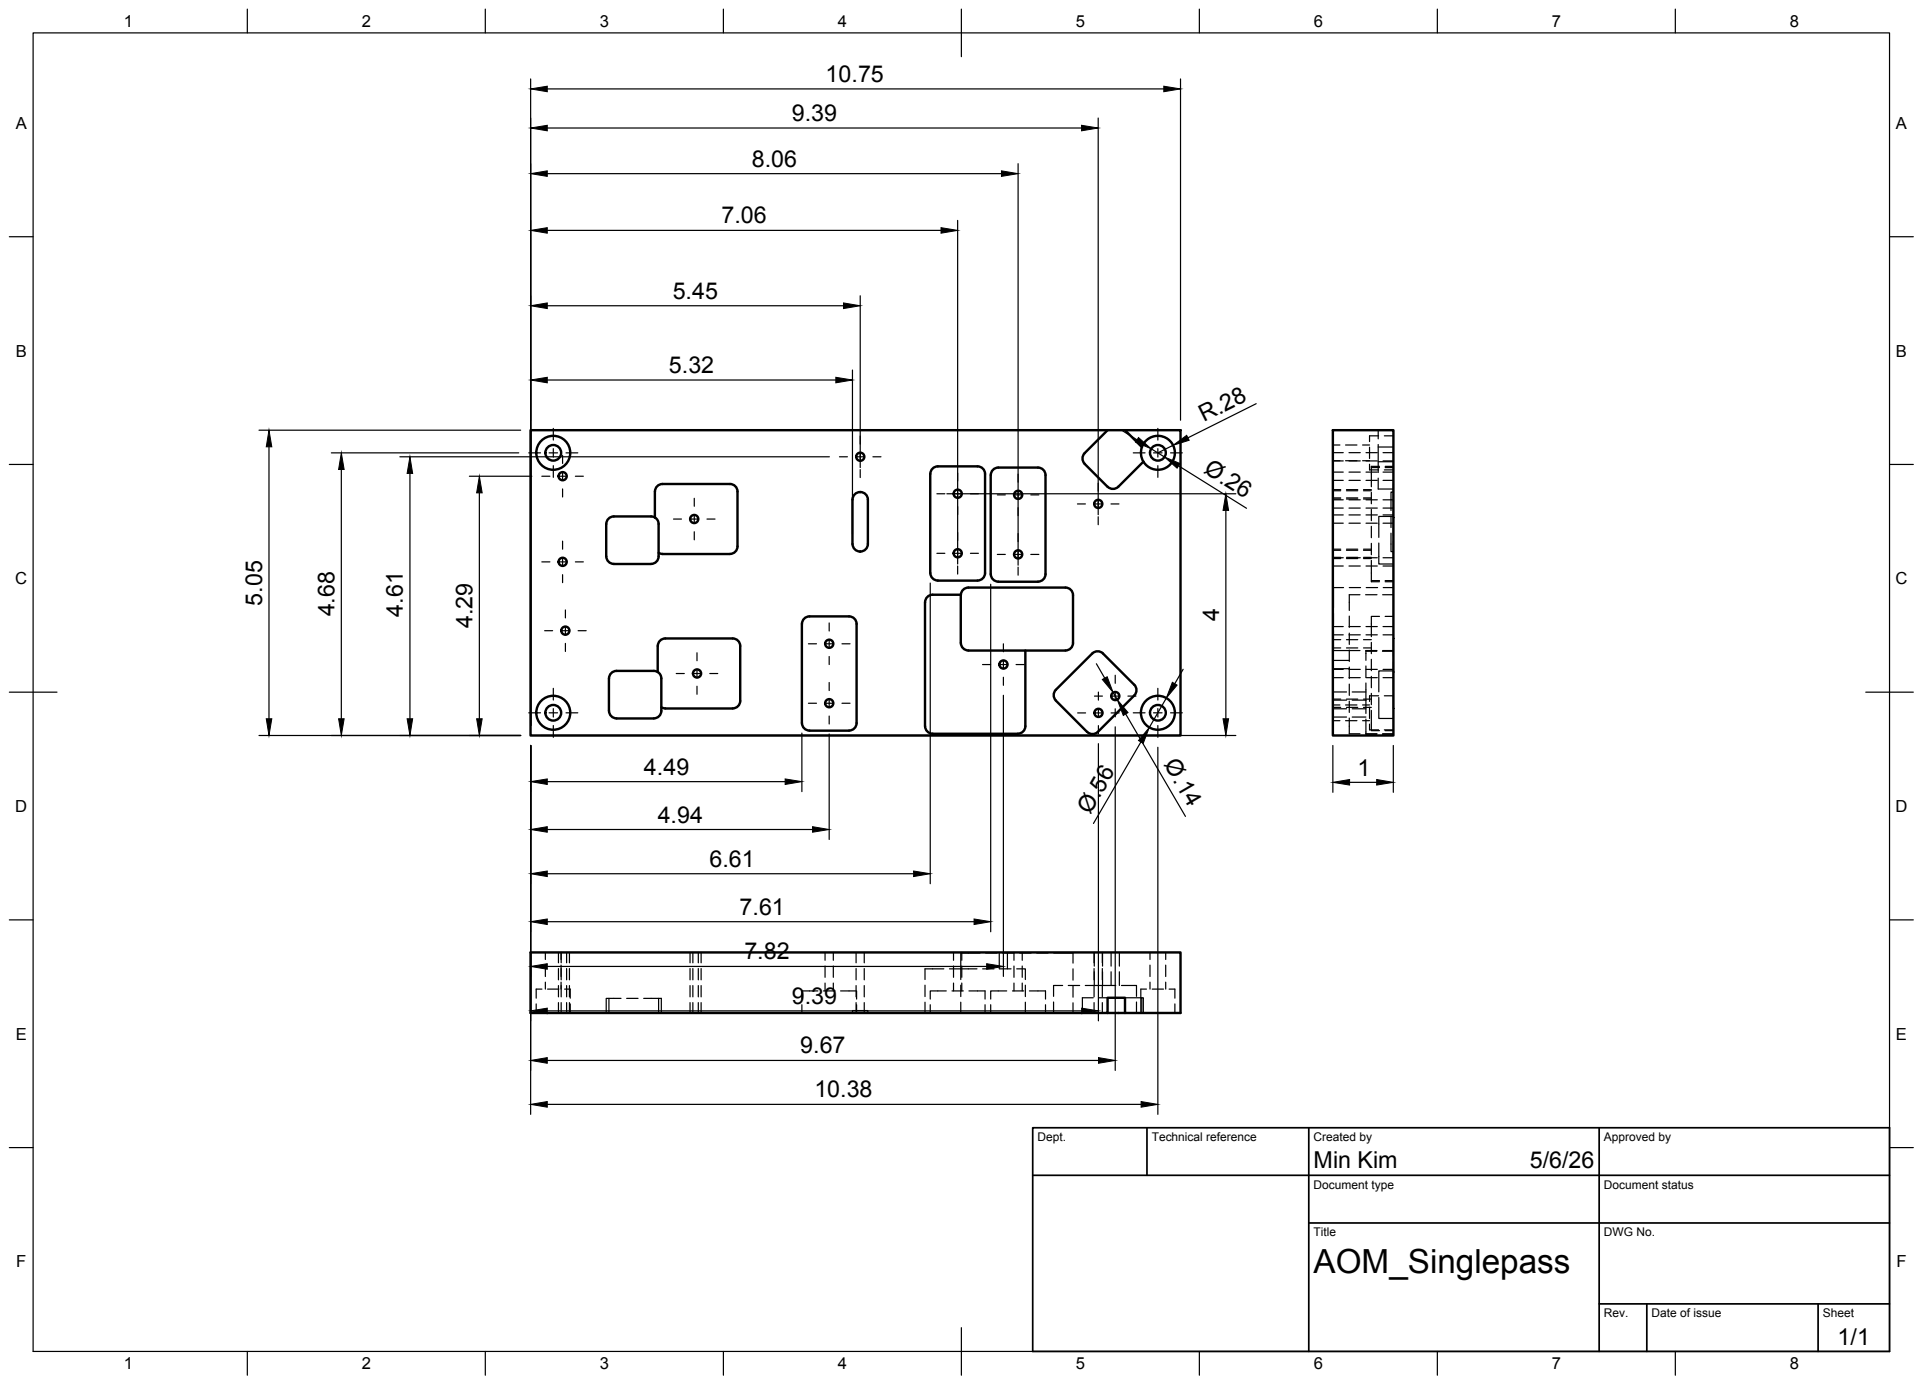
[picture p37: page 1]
Title; DWG No.; Rev.; Date of issue; Sheet

Dept. | Technical reference | Created by Min Kim 5/6/26 | Approved by

Document type | Document status

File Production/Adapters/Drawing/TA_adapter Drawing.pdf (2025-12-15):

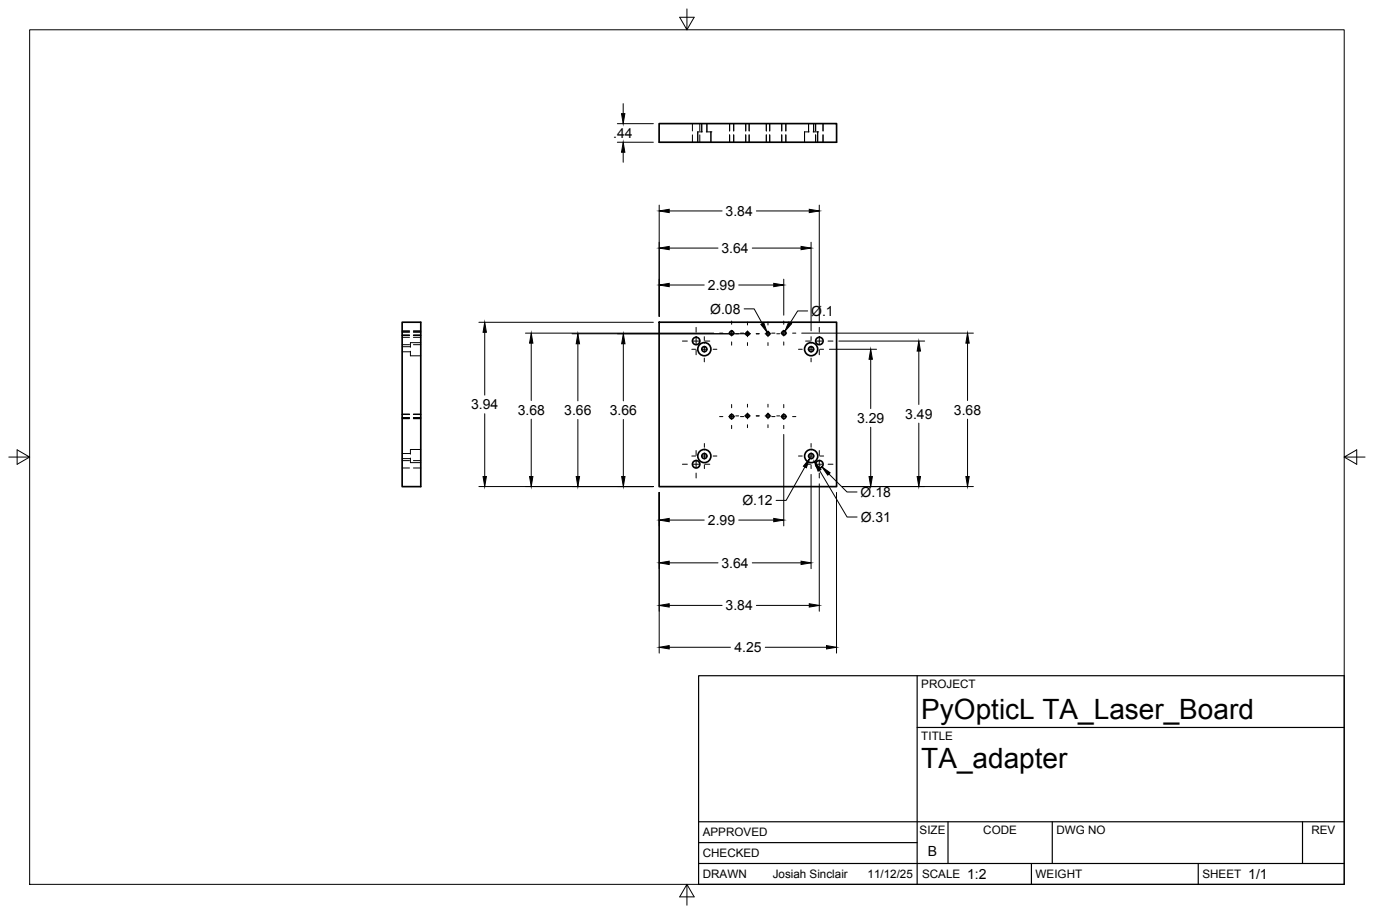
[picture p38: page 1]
SIZE; CODE; DWG NO; REV; Josiah Sinclair; PyOpticL TA_Laser_Board

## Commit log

2025-08-15 Upload all the python macros
    [BB05-E03-Step.step, BW20M.stl, C220TMD-A-Step.stl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]
2025-08-15 Upload the stl folder and optomech.py
2025-08-15 adjust the width of post_ta board to prevent possible overlapping of shutters
2025-08-15 uploading the adapter files
    [AOM_Adapter.step, Cube_Mount.step, Iris_Mount.step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]
2025-10-21 Updated parts list
    [AOM_Board.xlsx, Laser_Board.xlsx, Reference_Board.xlsx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]
2025-12-01 Organized the files.
    [AOM_Adapter.step, Cube_Mount_0.5inch.step, Cube_Mount_10mm.step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]
2025-12-10 Update the baseplate step file
    [AOM_Baseplate.step, Repumper_Baseplate.step]
2025-12-13 Add countersink hole in TA adapter
    [TA_adapter.step]
2026-04-07 Add optical lattice baseplate definition
    This script defines the laser board we will use to generate a 1D optical lattice in the room temperature neutral atom experiment. Notably, each of the 2 beams gets their own AOM.
2026-04-07 Added script that defines baseplate for MOT+Repump Lasers
    This script defines the laser board baseplate we will use to generate the light (MOT+Re-pump) that goes into the MOT chamber in the room temperature experiment for cooling/trapping.
